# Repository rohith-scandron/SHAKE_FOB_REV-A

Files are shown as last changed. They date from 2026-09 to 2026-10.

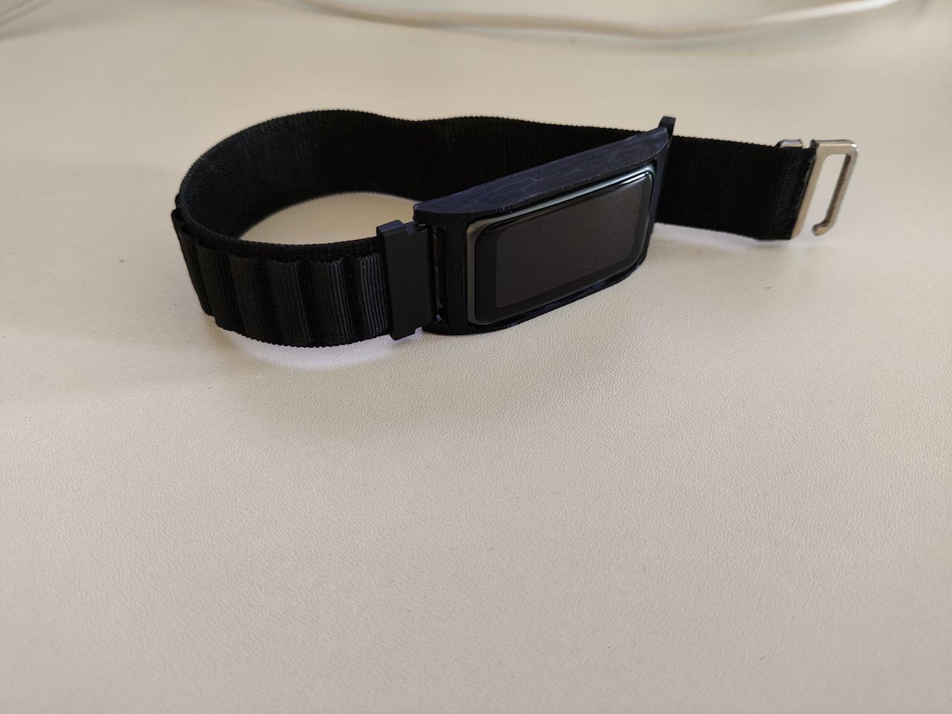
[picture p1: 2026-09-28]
22mm adapter for Huawei band 6 and Honor band 6 - 6260208/images/c12549b3-4bc7-4916-8d0e-d0bb0abc16f8.jpg

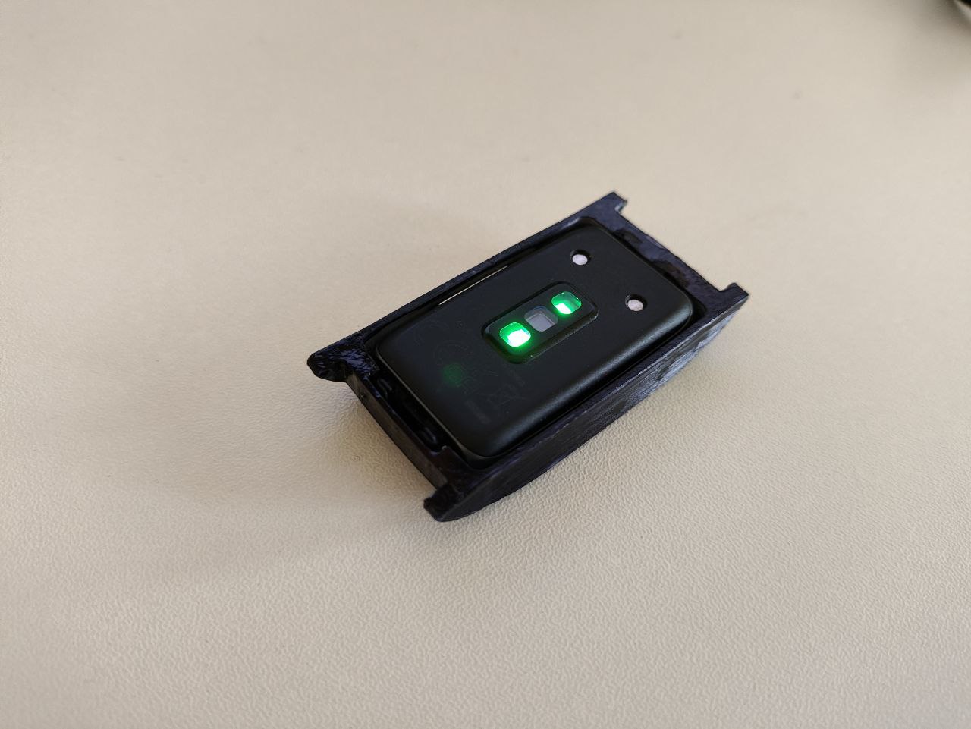
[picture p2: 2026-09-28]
22mm adapter for Huawei band 6 and Honor band 6 - 6260208/images/28dc4d0c-0de9-4cf2-bb80-d6530bd57ec2.jpg

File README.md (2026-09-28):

# SHAKE_FOB_REV-A

A PCB keychain: a shake-activated OLED "digital pet" fob. Sleeps at ~0 µA-class draw
until shaken, wakes and shows an emoji/gif on a small I2C OLED, advances to the next
one on a gentle shake, and sleeps again after 10 s idle. BLE included for a future
companion app to push new gifs. Charges and programs over USB-C. Built for JLCPCB
fab + assembly, optimized for the smallest board that still fits the parts.

## Key specs

| | |
|---|---|
| MCU | ESP32-C3FH4 (bare QFN32, 4 MB integrated flash, RISC-V, BLE 5) |
| Accelerometer | MMA8452QR1 (QFN-16 3×3 mm), transient (high-pass) wake interrupt, no polling needed. Replaced LIS2DH12TR, which is JLC "Standard PCBA only" |
| Charger | MCP73831T-2ACI/OT (SOT23-5), USB-C VBUS in, 147 mA charge rate (R_PROG = 6.8 kΩ) |
| 3V3 rail | XC6206P332MR (SOT23-3), ~1 µA Iq, 200 mA — sized for sleep-dominated duty |
| USB-C | TYPE-C-31-M-12, 16-pin, native USB D+/D− straight to the MCU (no CP2102/CH340) |
| Display | **off-board** — 0.96" 128×64 I2C OLED (SSD1306), 4 bare solder pads (GND/VCC/SCL/SDA), swappable |
| Battery | **off-board** — single-cell LiPo via 2 bare solder pads, user-sourced (the seller's cells come as bare leads, not a pre-terminated JST plug) |
| Buttons | RESET (EN→GND) and BOOT (GPIO9→GND), small SMD tactile — SuperMini-style |
| Board | 2-layer, target ≈ 25–30 × 18–22 mm, JLCPCB fab + SMT assembly |

All ICs above are on the JLCPCB parts library (LCSC part numbers in the BOM notes
below); the display and battery are intentionally *not* SMT parts — they connect
through headers/wires so either can be swapped without touching the PCB.

## BOM / JLCPCB parts library status

Checked against LCSC/JLCPCB directly (not from memory). Prices/stock are a snapshot
— reverify before ordering.

| Ref | Part | LCSC | JLCPCB library | Notes |
|---|---|---|---|---|
| U1 | ESP32-C3FH4, QFN-32-EP (5×5 mm) | C2858491 | Extended | 4233 in stock at check time |
| U4 | MMA8452QR1, QFN-16 (3×3 mm) | C11360 | Extended | Economic-PCBA OK, MSL1, 2,916 in stock. Replaced LIS2DH12TR (C110926: LGA, X-ray required → Standard PCBA only) |
| U3 | MCP73831T-2ACI/OT, SOT23-5 | C424093 | Extended (assumed) | not confirmed live, low risk either way |
| U4 | XC6206P332MR, SOT23-3 | C5446 | **Basic** | ~$0.02, ~1 µA Iq |
| U5 | USBLC6-2SC6, SOT23-6 | C7519 | Extended | USB ESD protection, use the genuine ST part |
| D2 | 1N4148WS, SOD-323 | C2128 | **Basic** | VBUS→SYS. Silicon, not Schottky, for nA reverse leakage on battery (see Power architecture) |
| Q1 | AO3401A P-MOSFET, SOT-23 | C15127 | **Basic** | BAT→SYS load-share switch (Microchip AN1149), ~14 mV drop vs ~0.3 V for a Schottky |
| R15, R16 | 1 MΩ 0402 battery-sense divider → GPIO3 | C26083 | **Basic** | + C19 100 nF; 2.1 µA |
| J1 | TYPE-C-31-M-12, USB-C 16-pin | C165948 | Extended | USB 2.0 subset only (VBUS/GND/D±/CC/SBU) |
| Y1 | 40 MHz crystal, 3225, C_L = 12 pF | **C5380316** (SOSET) | — | imported and confirmed 40 MHz on import; C13738 was mis-picked earlier (turned out to be 16 MHz) and has been removed |
| SW1, SW2 | TS342A2P tactile switch, 4×3×2 mm | C398055 | Extended | RESET + BOOT; checked for a Basic alternative, none found |
| TP1–TP4 | 4× bare solder pad (KiCad `TestPoint` lib) — OLED: GND/VCC/SCL/SDA | generic | n/a, not a real component | replaces a 2.54mm header — no connector to import, no BOM/CPL line |
| TP5–TP6 | 2× bare solder pad (KiCad `TestPoint` lib) — battery: BAT+/GND | generic | n/a, not a real component | replaces the JST-PH connector (below) — the actual battery source is bare leads, not a pre-terminated plug, so there's nothing to keep a connector for |
| ~~J3~~ | ~~S2B-PH-SM4-TB, SMD JST-PH 2-pin~~ | ~~C295747~~ | ~~Extended~~ | **dropped** — imported into the library, then superseded by TP5/TP6 once it turned out the battery isn't sold pre-terminated |
| ANT | Johanson 2450AT18A100E chip antenna | C89334 | — | in stock at check time; decided over a PCB trace, see Antenna below |
| — | RF matching, **chip-side only** (2×C 1.2–1.8pF + 1×L 2.0–3.0nH, 0201, pi network) | generic 0201 | Basic-class, commodity | antenna-side network deliberately dropped for a minimal BOM — see MCU wiring below |
| — | passives (0402/0603/0201 R/C) | generic | Basic-class, commodity | |

**11 Extended parts** after the two free swaps below (JLC BOM check,
2026-09-23): ESP32-C3FH4, MMA8452QR1, MCP73831, USBLC6-2SC6, TS342A2P,
USB-C (C165948), 40MHz crystal (C5380316), antenna (C89334), 1.5pF RF caps
(C1552), 2.2nH (C27122), 0402 LED (C71911). At $3 each that's ≈ **$33** in
loading fees. An earlier count of "5" was wrong. Free swaps with the same
footprint: 10k C25531 → **C25744** (R7–R9, R13, R14) and 100k C25530 →
**C25741** (R10), both Basic. Nothing else on the list has a Basic
equivalent in the same footprint.

**Assembly tier: Economic PCBA.** LIS2DH12TR (and its SC7A20 clone) is
flagged "Standard only" by JLC (LGA → X-ray, MSL3), so the accelerometer was
swapped to MMA8452QR1 (QFN, MSL1, Economic OK). It costs ~$1 more per part and
+3µA of sleep current, but saves ~$17 in Standard setup and the forced edge
rails.

## MCU wiring — verified against Espressif's datasheet + hardware design guidelines

Pulled `esp32-c3_datasheet_en.pdf` and the ESP32-C3 hardware design guidelines
directly (saved in [`datasheets/`](datasheets/)) rather than relying on memory.
Key points that affect the schematic:

- **Power pins**, each needs local decoupling: VDD3P3 (analog/RF, pins 2–3) — 10 µF
  + 0.1 µF (Espressif also suggests an LC filter inductor here for harmonic
  suppression — **dropped**, it's RF-certification margin rather than something
  needed for function, and the linear LDO feeding this rail is already low-noise);
  VDD3P3_RTC (pin 11) — 0.1 µF; VDD3P3_CPU (pin 17) — 0.1 µF; **VDD_SPI (pin 18)** —
  tie directly to 3V3 with a 1 µF cap, since the in-package flash on the FH4 needs
  VDD_SPI ≥ 3.0 V and this pin *cannot* be used as a GPIO on this variant. Add an ESD
  diode + ≥10 µF at the board's main power entrance too.
- **CHIP_EN**: must never float. Standard R=10 kΩ / C=1 µF RC delay to 3V3, RESET
  button pulls it to GND. Espressif's own note: on a slow/battery power rise, RC
  alone can be marginal — accepted as-is here (nearly every hobby ESP32 board ships
  with just RC), flagged as a known limitation rather than adding a supervisor IC.
- **Strapping pins** (GPIO2, GPIO8, GPIO9): GPIO9 gets an explicit pull-up
  (10 kΩ→3V3) *and* the datasheet explicitly warns not to put a capacitor on it, or
  the chip can drop into download mode — matters because BOOT button lands here.
  GPIO2 also gets a 10 kΩ pull-up ("recommended... due to glitches" even though it
  doesn't strictly gate boot mode). GPIO8 gets a 10 kΩ pull-up (R14): download boot needs GPIO8 = 1 (Table 3-3).
- **Crystal**: 40 MHz is compulsory (no internal option), ±10 ppm. Standard 2-pad
  crystal + 2 load caps. Espressif also suggests a 24 nH series inductor on the
  XTAL_P trace for harmonic suppression — **dropped**, same reasoning as the
  VDD3P3 filter above: their own guideline calls the value an "initial
  suggestion... adjust after an overall test," i.e. margin, not a requirement.
  ≥2 mm gap from the chip's clock pin, no vias on the clock trace itself, keep
  it away from the RF trace.
  **Load cap value, corrected:** the formula is `C_L = (C1×C2)/(C1+C2) + C_stray`
  (checked directly against Espressif's live HTML page — the PDF's text extraction
  had jumbled the fraction and put C_stray inside the denominator, which gave a
  wrong answer the first time around). With C1=C2=C, C_stray≈3 pF (typical PCB
  estimate), and our crystal's C_L=12 pF: `C = 2×(C_L − C_stray) = 2×(12−3) =
  18 pF`. **C1=C2=18 pF**, not the earlier 27 pF.
- **RF matching — deliberately minimal, one network not two.** Espressif's
  checklist describes two possible networks: a chip-side CLC ("must be
  placed close to the chip," no exception given) and a separate antenna-side
  CLC (which *does* have an explicit skip condition, if the antenna's
  impedance is already known to be 50Ω). The fully-by-the-book version of
  this design would have both — went there briefly, then cut back down by
  explicit request for a minimal board. **Kept the chip-side network only**
  (Espressif's generic bare-chip pi values: 1.2–1.8 pF / 2.0–3.0 nH /
  1.8–1.2 pF, 0201): a bare silicon RF pin with no matching at all is
  typically a bigger mismatch than a purpose-built antenna's nominal
  impedance drifting somewhat from board-layout differences, so this is the
  half that protects against the larger problem. **Dropped the antenna-side
  network** (Johanson's own T-network for this specific antenna, which their
  datasheet does recommend — see `docs/SCHEMATIC_BOM.md` Block 4e for the
  values, kept there for reference even though not populated). **Accepted
  trade-off, not a free simplification**: the antenna's real impedance on
  this board won't exactly match Johanson's 50Ω spec (measured on their own
  eval board), and that drift goes uncorrected — some range/efficiency traded
  for a smaller BOM, reasonable for a close-range, non-certified BLE keychain.

  Full derivation and the dropped network's values (kept for reference) in
  `docs/SCHEMATIC_BOM.md` Block 4e.
- **USB (GPIO18/19 = D−/D+)**: 22 Ω series resistors close to the chip; footprints for
  optional shunt caps and a D+ pull-up left unpopulated unless startup instability
  shows up on the bench.

### Antenna — decided: Johanson chip antenna

**Decision (confirmed with user 2026-09-22):** Johanson **2450AT18A100E** ceramic
chip antenna, LCSC C89334, in stock, ≈$0.54. The guidelines are explicit that a PCB
trace antenna needs EM simulation and real-world validation to get right — Espressif
doesn't publish a generic copy-paste trace for an arbitrary board shape, and
freehand-copying the SuperMini's antenna from a photo onto a different stackup has a
real chance of detuning it with no way for us to check. A chip antenna is a
purchasable SMD part with a vendor-validated footprint and matching network from
Johanson's own application note — a few cents of BOM for a much higher chance the
radio just works, with no lab equipment required. Still needs a copper/component
keep-out under and around it (per Johanson's app note), smaller than a full
PCB-trace keepout, so it doesn't reopen the board-size problem.

Note: the SuperMini board itself uses **ESP32-C3FN4**, which is now
**NRND (Not Recommended for New Designs)**. Good thing this board isn't cloning its
BOM — FH4 (already our pick) is the current, stocked part; "H" vs "N" also aren't
footprint-compatible, so a literal SuperMini clone wouldn't have dropped in anyway.

## Power / control architecture

```
USB-C VBUS (5V) ──┬──► MCP73831 ──► BAT ──► battery pads (TP5/TP6)
                  │                   │
                  │                   ├──► R15/R16 1M:1M ──► GPIO3 (battery sense)
                  │                   │
                  │                   └──► Q1 AO3401A (D→S) ──┐
                  │                          gate ◄── VBUS    │
                  ├──► D2 1N4148WS ─────────────────────────┴──► SYS ──► XC6206 ──► 3V3 ──► ESP32-C3, MMA8452Q, OLED
                  └──► R13 10k ──► GND (Q1 gate pull-down)
   CC1/CC2 ──5.1k──GND
   D+/D− ──────────────► MCU native USB

MMA8452Q INT1 ──► GPIO0 (RTC-capable, deep-sleep wake source, active-high)
MMA8452Q INT2 ──► GPIO1 (spare, wired for future use)
```

**Load sharing (Microchip AN1149).** USB present: Q1's gate is at VBUS, so
it's off. D2 feeds SYS and the battery charges alone, which lets the
charger terminate properly. USB absent: R13 pulls the gate low, Q1 turns
fully on, and SYS = BAT − ~14 mV. The board runs from USB with no battery
installed, and the battery never sees raw VBUS. Full reasoning and pin-out
are in [`docs/SCHEMATIC_BOM.md`](docs/SCHEMATIC_BOM.md) Block 2.

**Wake GPIO: GPIO0** (physical pin 4, `XTAL_32K_P`). ESP32-C3's RTC-IO pins — the
only ones that can wake the chip from deep sleep — are GPIO0–GPIO5 (the pins
powered by VDD3P3_RTC; datasheet §2.5, Table 2-1). Ruled out the others: GPIO2 is
a strapping pin (already has a pull-up for glitch immunity — simpler not to also
share it with an interrupt input at boot); GPIO4/GPIO5 double as JTAG (MTMS/MTDI);
GPIO0/GPIO1 are the pins for the *optional* 32.768 kHz RTC crystal, which this
board isn't populating, and the datasheet explicitly says those pins "can be used
as GPIOs" when that crystal is skipped (§1.3.5) — so GPIO0 is genuinely spare, not
a compromise. The MMA8452Q's INT pins are push-pull and always driven, so
**no pull resistor on either INT pin**. The old 100 kΩ pull-down (R10) is
deleted. It would fight the chip's power-on default (active-low, so idle
high) and waste 33 µA until firmware sets IPOL = 1.

- **Wake-on-shake is hardware, not polled.** The MMA8452Q's transient detector
  (high-pass filtered, so gravity and slow tilting are ignored) runs at 12.5 Hz in
  low-power mode (6 µA). A vigorous shake above ~1.5 g latches INT1, which wakes the
  ESP32-C3 from deep sleep. Once awake, firmware reprograms the same transient channel
  to a gentle threshold (~0.5 g at 50 Hz) for "next gif", then restores the wake
  settings before sleeping. There's only one transient channel, and it's all both
  gestures need. INT2 is wired but spare. Register values are in
  docs/SCHEMATIC_BOM.md Block 5.
- **Why a P-FET and not a second Schottky on the battery side.** The earlier
  D2+D3 diode-OR put a ~0.3V Schottky drop in the battery path. That raised
  the usable-battery floor to ~3.45V active, or ~3.6V during BLE. Q1 drops
  ~14mV, which puts the floor at **~3.1–3.2V active and ~3.3V during BLE**.
  Below that a LiPo has only a few % left, so this is effectively the whole
  cell. D2 is a **silicon** 1N4148WS on purpose: on battery it sits
  reverse-biased at ~4V, and the 1N5819WS Schottky leaks ~6–7µA there at
  25°C (read off its datasheet curve). That's over half the sleep budget.
  The 1N4148WS leaks nA. Its higher forward drop only applies on USB, where
  there's headroom to spare.
- **XC6206 (200mA) stays, with two firmware rules.** The ESP32-C3 datasheet
  only tables Wi-Fi TX current: **335mA peak @ 21dBm**, far over 200mA. So:
  **never enable Wi-Fi**, and **cap BLE TX at 0dBm**. The datasheet has no
  BLE figure, so measure the real peak at bring-up. Normal operation (CPU +
  OLED, no radio) is ~40–45mA, comfortably inside the rating. RT9013 (500mA)
  was rejected because its ~25µA Iq would roughly triple sleep current. An
  earlier "~650mV droop at 10µF, go to 47µF" derivation was withdrawn: it
  rested on an invented 50µs LDO response time. C9 = 10µF + C10 = 0.1µF is
  Espressif's reference decoupling for VDD3P3.
- **GPIO8 pull-up (R14, 10k to 3V3).** It's a strapping pin, and download
  mode needs GPIO8 = 1. In deep sleep the USB-CDC port disappears, so BOOT +
  RESET is the recovery path, and it must be reliable.
- **Battery sense (R15/R16/C19 → GPIO3).** Lets firmware stop waking the
  display below ~3.3V and show a battery icon, instead of brownout-looping
  the cell down to its protection cutoff.
- **No physical power switch.** Sleep budget, every figure sourced from the actual
  datasheet (see Battery life below, not hand-waved): **≈14.4 µA typical, board only**. Shelf
  drain from our own electronics is a non-issue at that level — LiPo self-discharge
  dominates over it. Revisit if a firmware bug (e.g. polling instead of interrupt-driven
  wake) makes this wrong.
- **No onboard battery protection IC.** Assumes the LiPo cell has its own protection
  PCB, which is standard for small hobby packs. **Confirm this once a battery is
  picked** — an unprotected cell needs a DW01+FS8205 (or similar) added.

## Battery life — 300 mAh cell

Every current figure below is from the actual component datasheet (all saved in
[`datasheets/`](datasheets/)), not estimated:

| Contributor | Typ. current | Source |
|---|---|---|
| ESP32-C3 deep-sleep (RTC timer + RTC memory only) | 5 µA | Espressif datasheet, Table 5-9 |
| MMA8452Q low-power mode, ≤12.5 Hz ODR (watching for a shake) | 6 µA | NXP datasheet, Table 3 |
| XC6206 LDO quiescent current | 1.0 µA | Torex XC6206 series spec (converged across distributor-hosted copies; direct Torex PDF was blocked from this environment) |
| MCP73831 leakage into BAT when USB is unplugged | 0.25 µA (2 µA max) | Microchip datasheet, "Battery Discharge Current," V DD < (V BAT − 50 mV) condition — **not** the 53 µA figure floating around online, which is a different spec ("Charge Complete, No Battery," current from V DD, not from the battery) |
| D2 reverse leakage, 1N4148WS @ ~4 V | ~0.01 µA | nA-class. A 1N5819WS here would be ~6–7 µA (Hottech datasheet curve) |
| Battery divider R15 + R16 (2 MΩ) | 2.1 µA | 4.2 V / 2 MΩ |
| Q1 / R13 | 0 | VBUS is 0 V on battery |
| **Total sleep current (board)** | **≈14.4 µA typ** | **+ OLED module in display-off (not budgeted — measure it)** |

**Pure shelf life** (never touched): the cell's own protection IC (~3 µA,
DW01-class) and LiPo self-discharge (~1–2 %/month ≈ 4–8 µA equivalent) are
as big as the board itself. A realistic shelf estimate, cell untouched, is
**~1–1.5 years**, minus whatever the OLED draws asleep.

**Real-world battery life is dominated by usage, not sleep current.** Per wake event
(OLED + MCU active for the spec'd 10 s, no radio — BLE is rare per your last note):
ESP32-C3 active ≈ 20 mA (Espressif Table 5-8, Modem-sleep/CPU-running range is
13–23 mA depending on clock and load) + SSD1306 OLED ≈ 20 mA (content-dependent,
typical hobbyist figure, not datasheet-sourced) ≈ **40 mA for 10 s ≈ 0.11 mAh/wake**.

| Wakes / day | mAh/day (wakes + sleep baseline) | Battery life |
|---|---|---|
| 10 (a few deliberate check-ins) | ~1.6 | **~6 months** |
| 30 (frequent play + some incidental jostling) | ~3.8 | **~2.5 months** |
| 100 (worst case — threshold too sensitive, triggers on walking/bag movement) | ~11.6 | **~26 days** |

**The single biggest lever on battery life is the shake-detection threshold**, not
any hardware choice already made — a threshold tuned to reject normal carrying
motion (walking, keys jingling in a pocket) versus one that only catches a
deliberate vigorous shake is roughly a 4–10× difference in real-world runtime. This
needs bench tuning once hardware exists; it can't be fully predicted on paper.

## Architecture decisions

| Decision | Rationale |
|---|---|
| Bare ESP32-C3FH4, not the MINI-1 module | User pointed at the ESP32-C3 "SuperMini" board as the size reference — that board uses the bare chip, not the pre-shielded module. Smaller and cheaper, at the cost of doing the RF front-end ourselves (see MCU wiring / Antenna below). |
| Chip antenna, not a hand-copied PCB trace | Confirmed with user. Espressif's own guidelines say a PCB trace antenna needs EM simulation + real hardware validation, which we can't do. A vendor-validated ceramic chip antenna (Johanson 2450AT18A100E, ~$0.54) is a few cents for much higher confidence it just works — reasonable even though BLE itself is a rarely-used, nice-to-have feature here, precisely because it's cheap enough not to be worth the risk either way. |
| Antenna keepout: tighter than Espressif's full 15 mm recommendation | 15 mm clearance in every direction would dominate the board size on something this small. The chip antenna's own keep-out (per its application note) is smaller than the bare-trace figure, and SuperMini-class boards prove a tight keepout still works for short-range BLE. Accepted trade: reduced RF range, irrelevant for a phone held next to a keychain. |
| MMA8452QR1 over LIS2DH12TR | LIS2DH12TR (and the SC7A20 clone) are JLC "Standard PCBA only" (LGA → X-ray, MSL3). The MMA8452Q is QFN, MSL1, Economic-assemblable, in stock, and has a high-pass transient detector made for shake wake. Costs: 3×3 mm vs 2×2 mm, ~$1 more, and 6 µA vs 3 µA asleep. The 2×2 MMA8652FC/MMA8653FC would be better but were out of stock (2026-09-23). |
| XC6206P332MR over AMS1117 / a plain 662k-style LDO | JLCPCB Basic part, ~1 µA quiescent current. AMS1117's ~5 mA quiescent draw alone would blow the sleep budget by >250×. |
| MCP73831 over TP4056 | SOT23-5 is smaller than TP4056's SOP-8, and board area is the constraint here. Trade-off: no onboard load-disconnect/protection — see the protection-IC note above. |
| Native USB (no CP2102/CH340 bridge) | ESP32-C3 has an on-chip USB-Serial-JTAG controller; wiring D+/D− straight to it gives USB-CDC programming and a serial console for free, and drops a chip + its passives from the BOM. |
| OLED and battery off-board via solder pads | Per instruction — keeps the option to change display size later without a respin, and neither part is realistically JLCPCB-SMT-placeable-and-reliable at this end of the market anyway (small COG/FPC displays are usually hand-placed even on boards that do put them in the BOM). Pads instead of connectors on both, once it was clear neither the OLED nor the battery arrives pre-terminated for one. |

## Open items (before this is ready for schematic capture)

**Resolved this pass:**
- ~~Antenna approach~~ → **decided and confirmed:** Johanson 2450AT18A100E chip antenna
- ~~40 MHz crystal~~ → **SOSET C5380316**, confirmed 40 MHz on import (an earlier candidate, YXC C13738, turned out to be 16 MHz and was removed from the library)
- ~~Library import~~ → all 9 distinctively-numbered parts imported into `ESP32_C3_FOB/libs/lcsc/` via the LCSC manager plugin, symbol+footprint+3D model each — see `docs/SCHEMATIC_BOM.md` for the KiCad symbol/footprint names
- ~~RF matching network~~ → settled on **chip-side pi network only** (Espressif's generic values), one network not two — antenna-side T-network (Johanson's values) deliberately dropped for a minimal BOM, accepted as a real trade-off not a free simplification. VDD3P3 filter and crystal series inductors also dropped as unneeded RF-certification margin.
- ~~JLCPCB part availability~~ → full table above, all parts orderable today
- ~~Sleep-current budget~~ → re-derived from actual datasheets: ≈12.25 µA typ (see Battery life) — corrects the earlier hand-waved 17 µA figure
- ~~Battery life estimate~~ → see Battery life section; dominated by wake frequency, not sleep current
- ~~Wake GPIO~~ → **GPIO0**, see Power/control architecture above for why
- ~~R_PROG~~ → **battery confirmed at 300 mAh; R_PROG = 6.8 kΩ → 147 mA (≈0.5C)**,
  from MCP73831 datasheet §5.2.2: `I_REG(mA) = 1000 × V / R_PROG(kΩ)`. 0.5C chosen
  over 1C (300 mA, R_PROG = 3.3 kΩ) for better cycle life on a small cell — swap one
  resistor if faster charging matters more than longevity.

**Still open:**
- **Board outline and JLCPCB panelization** — anything under 70×70 mm needs a panel
  (mouse-bites or V-cut) for SMT assembly; this board will need one designed once
  the outline is fixed.
- Charge-status LED on MCP73831 STAT — included by default, cut if it doesn't fit.
- CHIP_EN RC-only power-up timing on battery power — accepted risk, see MCU wiring above.

## Repository layout

| Path | Contents |
|---|---|
| `SHAKE_FOB_REV-A.kicad_pro/.kicad_sch/.kicad_pcb` | KiCad project (not created yet) |
| `libs/lcsc/` | Project-local LCSC symbols/footprints/3D models |
| `docs/` | Working notes |

## Status

**Architecture and BOM defined. Schematic capture not started.**
# SHAKE_FOB_REV-A

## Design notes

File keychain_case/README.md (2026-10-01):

# HUAWEI Band 6 keychain case

A keychain frame for the HUAWEI Band 6: the four sides only, no strap mounts, flat ends
and a keyring loop. The screen and the heart-rate sensor stay uncovered.

| File | |
|---|---|
| `band6_keychain_case.step` | CAD (STEP) |
| `band6_keychain_case.stl` | ready to slice |
| `band6_keychain_case.py` | CadQuery source, all sizes at the top |
| `preview.png` | renders |

Outside size: **27.4 × 56.7 × 10.2 mm** (including the loop).

## Fit

The fit geometry was measured from the proven Band 6 frame
[thing:6260208](https://www.thingiverse.com/thing:6260208) and rebuilt as a clean solid.
The rebuild matches the reference surface to a median deviation of 0.003 mm.
- 25.38 × 42.6 mm cavity with 1.0 mm side walls and the same curved screen-side edge
- button opening in the same spot
- the two internal tongues that clip into the watch's own strap slots. These are what
  hold the watch in the frame, so they are kept.

What changed: the 22 mm spring-bar ears are removed, the ends are closed flat, the four outer
corners are rounded (5 mm radius), and a round keyring eye is added. The eye has a wide triangular base
so the pull goes into the solid end corners.

With the keyring at the top and the screen facing you, the button opening is on the right
(`BTN_SIDE = 1`; `-1` moves it to the other wall, `RING_END` swaps the loop's end). It is a round eye (9 mm outside,
4.6 mm hole) set close to the case, so it sticks out only 7.2 mm past the case end.

A 0.8 mm inward ledge runs along the back edge of the two long sides (`LIP_W`, `LIP_T`).
The short ends have no ledge, so the watch can be tilted in end first past the tongues. The watch is pushed in
from the screen side and stops on it, and it can't fall out the back. The ledge is added
under the old back face, so the watch sits at the same height and the tongues still line
up with its strap slots; the case is 0.8 mm thicker. The heart-rate sensor stays uncovered.

## Printing

- Print with the flat back face on the bed. It needs no supports: the tongue pockets are
  short bridges.
- Material: PETG or PLA (the reference was printed rigid), 0.4 mm nozzle, 0.12–0.16 mm
  layers, 3+ walls.
- Fitting: from the screen side, slide one end's tongue into the watch's strap slot, then
  press the other end in until it clicks and the watch sits on the back ledge.
- If it is too tight, set `CLEAR = 0.1` in the script and re-run
  `python3 band6_keychain_case.py`.

## License

Derived from "22mm adapter for Huawei band 6 and Honor band 6" by M7md_says_hello
(thing:6260208), licensed **CC BY-SA**. This derivative is shared under the same license.

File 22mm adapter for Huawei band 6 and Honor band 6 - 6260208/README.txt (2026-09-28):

22mm adapter for Huawei band 6 and Honor band 6 by M7md_says_hello on Thingiverse: https://www.thingiverse.com/thing:6260208

Summary:
22mm adapter for Huawei band 6 and Honor band 6

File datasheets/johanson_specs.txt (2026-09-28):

=== PAGE 1 ===
P/N:  2450AT18A0100001E 
Legacy P/N: 2450AT18A100 
Doc# 36S0021A 
Page 1 of 6 / Revision 4.0 
Datasheet: 2450AT18A0100001E 
johansontechnology.com 
4001 Calle Tecate • Camarillo, CA 93012, USA • +1.805-389-1166 
2024 Johanson Technology, Inc.  All Rights Reserved 
2.45 GHz RF Chip Antenna 
•
2.4 – 2.5 GHz Operational frequency
•
Bluetooth, WLAN
•
SMD, EIA 1206
•
Corner mount
•
RoHS compliant and AEC-Q200 Qualified available
Johanson Technology, Inc. (JTI) miniature RF ceramic chip antennas 
are made using Low Temperature Co-fired Ceramic (LTCC) technology 
which has the ability to embed low and high dielectric constants inside 
our antenna. This  enables our components to have high detuning 
resilience and stability over extreme temperatures (~2ppm). 
General Specifications1 2 
Maximum Ratings 
1 Typical value represents average measurement at 25°C. Min./Max. values represent measurements over specified operating temperature. 
2 General specifications measured on Johanson’s evaluation board P/N 2450AT18A0100001CE1.  
Passband Frequency (MHz) 
2400 - 2500 
Impedance (Ω) 
50 
Return Loss (dB) 
9.5 Min. 
Peak Gain (dBi) 
1.5 Typ. 
Average Gain (dBi) 
0.0 Typ. 
Average Radiated Efficiency (%) 
74 
Power Capacity (W) 
3 Max. (CW) 
Operating Temperature (°C) 
-40 to +125
Recommended Storage Conditions post-installation (°C) 
-40 to +125
Recommended Storage Conditions and Period for Unused T&R Product 
45% - 75% RH 
+5 to +35 °C
18 Months Max. 
PCB Corner 
Recommended mounting locations for this antenna 
=== PAGE 2 ===
P/N:  2450AT18A0100001E 
Legacy P/N: 2450AT18A100 

Doc# 36S0021A 
Page 2 of 6 / Revision 4.0 
Datasheet: 2450AT18A0100001E 
 
johansontechnology.com 
4001 Calle Tecate • Camarillo, CA 93012, USA • +1.805-389-1166 
2024 Johanson Technology, Inc.  All Rights Reserved 
Mechanical Dimensions  

Terminal Configuration3 

3 The termination type is Nickel Tin. Go to: https://www.johansontechnology.com/ipcsoldering-profile for Typical Soldering Profile. 
 This terminal must be soldered for anchoring and mechanical stability. 
Pin Number 
Function 
1 
Feed 
2 
NC 
Bottom view 
Top view 
Side view 
② 
① 
a 
a 
L 
W 
T 
L
0.126
±
0.008
3.20
±
0.20
W
0.063
±
0.008
1.60
±
0.20
T
0.051
1.30
a
0.020
±
0.012
0.50
±
0.30
Inches
Millimeters
 +0.10/-0.20
 +0.004/-0.008

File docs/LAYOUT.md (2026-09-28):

# Layout guide — SHAKE_FOB_REV-A

Ref-des match the actual schematic. Rules are sourced from Espressif's
ESP32-C3 hardware design guidelines §1.4 and the Johanson 2450AT18A100E
datasheet (p.3), both in `datasheets/`.

---

## 0. Before placing anything

| Step | What |
|---|---|
| 1 | **Add C20 (1µF, C52923) + C21 (10nF, C15195) on VDDA pins 31/32** in the schematic, then press F8 (Update PCB from Schematic). The PCB currently has 48 footprints; the schematic has 55, going to 57. |
| 2 | Stackup: **2 layers, 1.6mm** (the cheap default, kept on purpose for a hobby board). |
| 3 | **Shrink the existing 3.3V zone on F.Cu.** It currently covers the whole board. Redraw it as a bounded region (see Zones below), because a board-wide 3.3V pour puts 3.3V copper right against the RF trace, the crystal and the antenna. |
| 4 | Zones: **GND on both layers** plus the bounded 3.3V region on top. B.Cu is the ground plane, so keep it as unbroken as possible. |
| 5 | **Change R1, R2 (5.1k) and R6 (1k) from 0201 to 0402**, see the box below. |
| 6 | Enter the Board Setup values in section 0a. |

> **Why 0201 has to go.** JLC **Economic PCBA** (the cheap one) only
> places parts down to **0402**. A single 0201 forces **Standard PCBA**,
> which needs a board ≥70×70mm or a panel with edge rails, plus fiducials
> and a higher setup fee. Every other part on this board is already 0402 or
> larger.
> - R1, R2 → 5.1kΩ 0402 **C25905** (Basic)
> - R6 → 1kΩ 0402 **C11702** (Basic)
>
> For the footprint, reuse any R0402 footprint already in your lib (e.g.
> `lcsc_footprints:C25531_R0402`). The land pattern is identical.
>
> Economic PCBA also means: one side only (already the plan), 0.8–1.6mm
> thick, board ≥10×10mm, and **no fiducials or edge rails needed**.

---

## 0a. Board Setup values (JLC 2-layer, 1oz, 1.6mm)

JLC limits below are from jlcpcb.com/capabilities (checked 2026-09-23).
The chosen value leaves margin over the absolute minimum, because
running at the limit is where yield drops.

### Design Rules → Constraints

| Setting | JLC min | **Use** |
|---|---|---|
| Minimum clearance | 0.10 | **0.15** |
| Minimum track width | 0.10 | **0.15** |
| Minimum connection width | — | **0.15** |
| Minimum annular width (via) | 0.05 | **0.10** |
| Minimum via diameter | 0.25 | **0.50** |
| Copper to hole clearance | 0.20 (via hole → track) | **0.20** |
| Copper to edge clearance | 0.20 (routed edge) | **0.30** |
| Minimum through hole | 0.15 | **0.30** (0.3mm drill is JLC's no-extra-cost size) |
| Hole to hole clearance | 0.20 (via), 0.45 (pad holes) | **0.25** |
| Silk: min text height / thickness | 1.0 / 0.15 | **1.0 / 0.15** |
| Silk to pad (mask) clearance | 0.15 | **0.15** |

### Design Rules → Solder Mask/Paste

| Setting | **Use** | Why |
|---|---|---|
| Solder mask expansion | **0** | JLC plots your mask 1:1 |
| Solder mask min web width | **0.10** | JLC min mask bridge, green |
| Tent vias | **on, both sides** | JLC fills tented vias with mask, so no shorts under parts |

With a 0.5mm pitch QFN/LGA, the pad gaps are ~0.2–0.25mm, above the 0.1mm
bridge, so mask dams stay between pins.

### Pre-defined Sizes — 3 widths, 1 via

| Tracks | Via (dia / drill) |
|---|---|
| **0.2** signals · **0.4** power · **0.6** RF trace only | **0.6 / 0.3** everywhere, including the EP grid |

### Net Classes — just 2

| Class | Track | Clearance | Via | Nets |
|---|---|---|---|---|
| **Default** | 0.2 | 0.15 | 0.6 / 0.3 | everything not listed below |
| **Power** | 0.4 | 0.2 | 0.6 / 0.3 | `VBUS`, `BAT`, `V_SYS`, `3.3V`, `GND` |

- **0.2mm fits everywhere,** including the QFN and LGA pads (~0.25mm wide),
  so no neck-downs are needed. USB D+/D− and the crystal lines are just
  Default, routed carefully by hand.
- **0.4mm for power** handles ~1A on 1oz outer copper. The biggest current
  here is ~200mA.
- **RF is drawn by hand at 0.6mm.** It's one ~4mm trace, so it doesn't need
  its own class. With the 0.2mm zone gap it comes out at ~63Ω. That's fine
  at this length (a true 50Ω line would be ~1.2mm wide).
- **By hand, no DRC rule:** no vias on the RF trace or the crystal lines.

### Zones (fills)

| Zone | Layer | Area | Priority |
|---|---|---|---|
| **GND** | B.Cu | whole board | 0 |
| **GND** | F.Cu | whole board | 0 |
| **3.3V** | F.Cu | **bounded region only**, see below | 1 (higher) |

Settings for all zones: clearance **0.2**, min width **0.2**, thermal
reliefs (spoke 0.3, gap 0.2), remove islands **always**. For U3, C14 and
C15, set zone connection to **Solid** in the footprint properties.

**3.3V fill: allowed, but fence it in.** Draw the 3.3V zone outline only
around the LDO → C9 → ESP32 power-pin area. Keep it **off**:
- the antenna corner, the RF trace and C14/L3/C15
- the crystal and C12/C13
- the USB D+/D− pair

Those areas need **top-layer GND** next to them: the RF trace uses the top
GND as its side walls, and the crystal needs a clean ground ring. The
whole-board top GND zone automatically fills everything the 3.3V zone
doesn't cover, because the higher-priority zone wins where they overlap.
The bottom layer stays 100% GND, which is Espressif's 2-layer rule.

### Antenna keepout

Rule area 6.5 × 6.5mm at the antenna corner, **F.Cu + B.Cu**. Tick keep out
*tracks*, *vias*, *copper pours*. **Untick** *pads* and *footprints*, so
AE1 itself can sit inside it.

### Vias in the QFN EP

9 vias, **0.6 / 0.3**, 3×3 grid at ~1.1mm pitch inside the 3.7mm EP. These
can't be tented because they're in a pad. A little solder wicks down them,
which is normal and harmless on a ground/thermal pad.

**2-layer rules (Espressif §1.4.1–1.4.2, two-layer design):**
- **B.Cu = ground.** Don't place parts on the bottom and keep traces there
  to a minimum. Any bottom trace must be short, and **never under the chip,
  the crystal, the RF trace or the antenna feed.** A long bottom trace cuts
  the ground plane and the return current has to detour around it.
- **Route power on the top layer**, including the 3V3 branches to each
  chip pin. Use vias to the bottom only when there's no other way.
- Put GND vias everywhere between top-layer pour and bottom plane: at every
  cap's GND pad, around the RF trace, around the crystal, and along the
  board edges.

**RF trace width on 2-layer:** a true 50Ω coplanar trace on 1.6mm FR4 is
~1.2mm wide with the 0.2mm zone gap (calculated for εr 4.4–4.6). A 0.6mm
trace is ~63Ω. At 2.44GHz the wavelength in this line is ~76mm, so a trace
under ~4mm (λ/20) is electrically too short for 63Ω vs 50Ω to matter.
**Decision: route it at 0.6mm and keep it short** by putting U3 right next
to the antenna corner. If the RF trace can't be kept short, make it
1.0mm wide instead.

---

## 1. Floorplan — decide the stack first

The 0.96" OLED module is ~27×28mm, so the fob is at least that size anyway.
The PCB can be the same width at no size cost.

**The one hard mechanical rule:** the antenna corner must **not** sit
behind the OLED module or the LiPo pouch. Both are large ground/metal
sheets and will detune it. Let the antenna corner stick out ~7mm beyond the
display/battery stack.

```
 ┌───────────────────────────┐
 │ (O)            ┌─────────┐│  ← 6.5×6.5mm corner: NO copper on ANY layer
 │ keyring        │   AE1   ││     antenna long axis along the board edge,
 │ hole           └────▲────┘│     feed pin 1 toward the ground plane
 │                     │ π   │  ← C15 / L3 / C14 right at U3 pin 1
 │   X1 ◄2mm+  ┌─────┐─┘     │
 │             │ U3  │   U4  │
 │   C20/C21   └─────┘       │
 │  OLED pads: GND VCC SCL SDA (2.54mm pitch)
 │  U2  Q1 D2   U1  LED1     │
 │ SW1 SW2   BAT+ BAT−   D1  │
 │          [ USB-C ]        │
 └───────────────────────────┘
```

- **Antenna end = far end from USB-C.** The USB shell and cable are metal.
- **Keyring hole:** NPTH ~4mm, in the top corner *opposite* the antenna,
  ≥2mm of board to the edge, copper keepout ~1mm around it. Never put it at
  the USB end, or the ring blocks the plug.
- **Buttons (SW1 RESET, SW2 BOOT)** must stay reachable after the OLED and
  battery are mounted. Put them at the USB end, which has to stay exposed
  anyway.
- **All SMT on the top side.** A single side means one assembly pass,
  which is cheaper.

---

## 2. Block by block

### RF + antenna (do this first, everything else fits around it)

| Rule | Source |
|---|---|
| AE1 in a board **corner**, long axis parallel to the edge, ~1mm in from it | Johanson p.3 |
| **6.5 × 6.5mm copper-free area** around AE1 on **both layers**. Use a KiCad Rule Area: keep out tracks, vias and zone fill, but allow footprints | Johanson p.3 |
| AE1 pin 1 (feed) faces the ground plane. Pin 2 (NC) gets its pad and solder but no connection | Johanson p.2 |
| U3 **pin 1 corner points at the antenna** | Espressif §1.4.4 |
| C15 (shunt, at pin 1) → L3 (series) → C14 (shunt) as close to pin 1 as possible, **zigzag** (the two caps not oriented the same way) | Espressif §1.4.4 |
| No 2nd-harmonic stub needed: "not required for 0402 and above", and these are 0402 | Espressif §1.4.4 |
| C14/C15 GND pads: a via right at each pad, solid connection (no thermal spokes) | Espressif §1.4.2 |
| RF trace from C14 to AE1: **top layer only, no vias, constant width, no branches, ≤4mm**, GND via fence on both sides at ~1mm pitch, solid bottom GND under it | Espressif §1.4.4 |
| Nothing else routed near the RF trace, on any layer | Espressif §1.4.9 |

### ESP32-C3 (U3) — pin sides and what goes on each

| Side | Pins | Place here |
|---|---|---|
| 1 | 1 RF · 2,3 VDD3P3 · 4,5 INT1/INT2 · 6 GPIO2 · 7 EN · 8 VBAT_SENSE | π network at pin 1, **C9 + C10 at pins 2/3**, R8 at 6, R7+C6 at 7, R15/R16/C19 near 8 |
| 2 | 9 SDA · 10 SCL · 11 RTC · 14 GPIO8 · 15 BOOT | C8 at 11, R14 at 14, R9 at 15. I2C heads toward U4 and the OLED pads |
| 3 | 17 VDD3P3_CPU · 18 VDD_SPI · 19–24 NC | C7 at 17, C11 at 18. No routing on this side, so it's free for the 3V3 feed |
| 4 | 25,26 USB · 29,30 XTAL · 31,32 VDDA | R3/R4 near 25/26, crystal off 29/30, **C20 + C21 at 31/32** |

- **EP (pin 33): ≥9 GND vias** (3×3 grid, 0.3mm drill), solid to the
  pour. Use a windowed paste pattern (~4 squares) so the QFN doesn't float
  on a solder blob.
- **Power:** 3V3 enters at **C9 (10µF) by pins 2/3**, then branches in a
  star **on the top layer** around the outside of the chip to each pin's
  own cap. Espressif: "a 10µF capacitor before the power trace enters the
  chip… then branch out in a star-shaped layout". Keep U2 close to that side
  so C9 doubles as the "main power entrance" cap. Side 3 (pins 19–24, all
  NC) has no other routing, so it's the natural path for the 3V3 branch to
  pins 17/18.
- Every decoupling cap sits on its own pin with a GND via at its pad.
  Cap first, then the via to the pin, never via → cap.

### Crystal (X1, C12, C13)

- **≥2mm gap between the crystal and the chip**, on the pin 29/30 side,
  toward the pin 25 end so it stays away from the RF corner.
- **No vias on XTAL_P/XTAL_N.** Short, direct, top layer.
- C12/C13 at the crystal's own pads, GND via right at each.
- **Nothing routed under the crystal on any layer.** Stitch GND vias
  around it. Keep it away from the antenna and from USB.

### USB (USBC1, D1, R1–R4)

- USB-C flush with the board edge, using the footprint's board-edge marker.
  EH shell tabs go to GND.
- **D1 (USBLC6) right behind the connector**, with a short, fat GND via.
- Tie DP1+DP2 and DN1+DN2 right at the connector. That needs one short
  bottom-layer crossover (every USB-C footprint does). Keep it under ~2mm,
  with a GND via next to each signal via.
- R3/R4 (22Ω) **near the chip side** (Espressif §1.4.8).
- D+/D− routed as a pair, equal length, on top over unbroken bottom GND.
  The ESP32-C3 is USB Full-Speed (12Mbps), so on traces this short,
  keeping the pair together matters more than hitting exactly 90Ω. On
  2-layer 1.6mm, true 90Ω isn't practical anyway.
- R1/R2 (CC 5.1k) right at the CC pins.

### Power path (U1, U2, Q1, D2, R13, C1–C5, LED1)

- Cluster at the USB end: USBC1 → C1/C3 → U1 and D2/Q1 → V_SYS → U2 → 3V3
  heading toward U3's pin 2/3 side.
- **C4 at U2 Vin, C5 at U2 Vout**, both within ~1mm of the pins.
- **C2 (10µF) right at U1 VBAT (pin 3).** It's the charger's stability cap.
- Q1, D2 and R13 next to each other between U1 and U2. Tracks at 0.4mm.
- U1 dissipates up to ~0.3W while charging, so give its VSS pin a copper
  pad and a couple of GND vias.
- BAT+ / BAT− pads (TP5/TP6) on an edge near U1, with **"+" and "−"
  clearly on silkscreen**. Reversed polarity kills the charger.

### Accelerometer (U4, C16–C18, R10)

- Near the middle of the board, **away from USB-C, the buttons, the keyring
  hole and the board edges**. Board flex from plugging in or pressing a
  button shifts an MEMS sensor's zero point.
- C16/C18 at VDD (pin 9), C17 at VDD_IO (pin 10).
- LGA-12, 0.5mm pitch: 0.15mm fan-out tracks, no vias under the part.

### Pads (TP1–TP6)

- OLED pads **TP1–TP4 in a row at 2.54mm pitch in your module's pin
  order**, so wires don't cross and the header can even solder straight
  in. Check your module first: some are GND-VCC-SCL-SDA, others
  VCC-GND-…
- Silk-label every pad.
- After soldering, glue over the wires for strain relief. That's the #1
  robustness item for something on a keyring.

---

## 3. Before ordering

- [ ] DRC clean, with "unconnected items" at zero.
- [ ] Antenna rule area empty of copper on both layers (check each layer
      on its own).
- [ ] No bottom-layer trace longer than a few mm, and none under U3, X1,
      the RF trace or AE1.
- [ ] Nothing routed under X1 or next to the RF trace.
- [ ] EP has ≥9 vias. Every cap has its GND via at the pad.
- [ ] USB-C front face at the board edge.
- [ ] Silkscreen: BAT +/−, OLED pin names, RST, BOOT.
- [ ] JLC CPL rotations checked in their preview (LCSC-library footprints
      are usually right, but check the QFN, SOT-23s, LED and diode
      polarity).

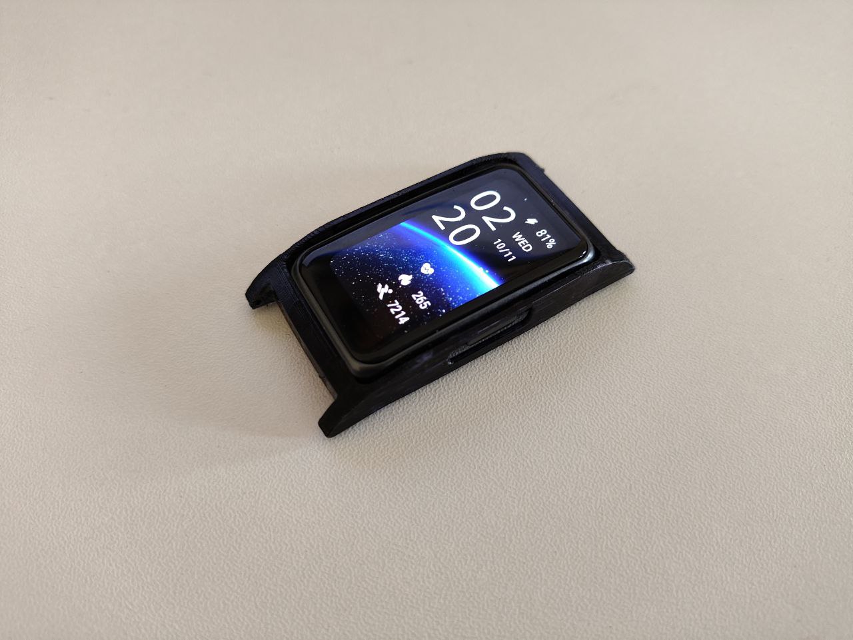
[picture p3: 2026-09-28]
22mm adapter for Huawei band 6 and Honor band 6 - 6260208/images/70614ff3-1db4-46b8-b5fa-840c29a9c139.jpg

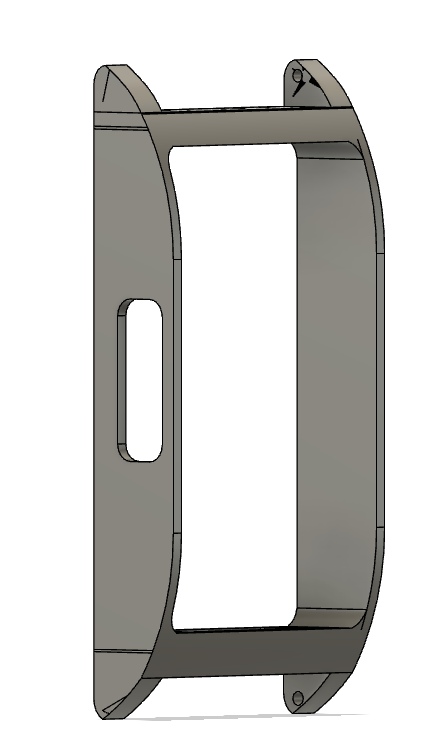
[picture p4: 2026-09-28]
22mm adapter for Huawei band 6 and Honor band 6 - 6260208/images/5cf072b8-9097-41da-a825-011a38e98a3d.png

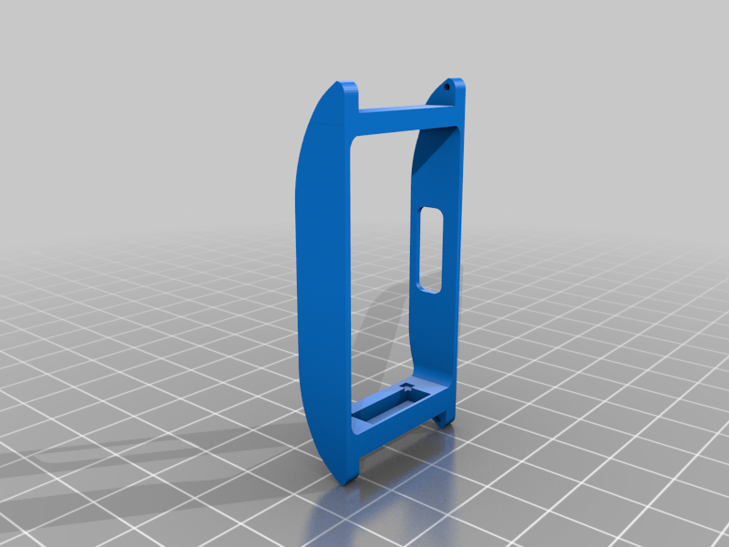
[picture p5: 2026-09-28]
22mm adapter for Huawei band 6 and Honor band 6 - 6260208/images/422cdf3e-c427-4954-85b6-9c759fb4e02e.png

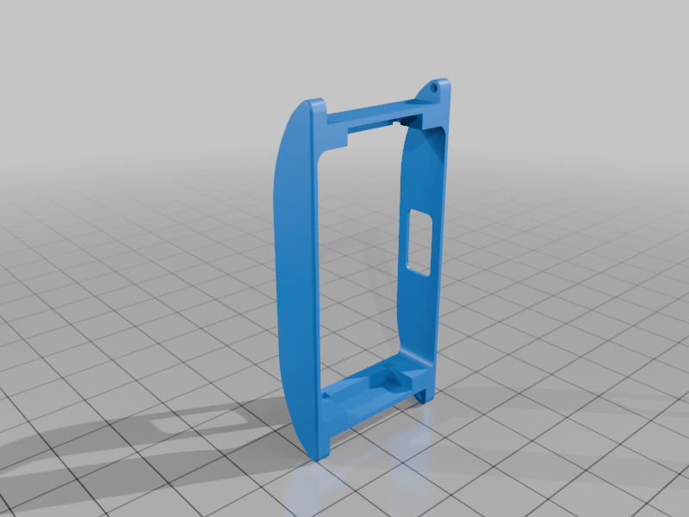
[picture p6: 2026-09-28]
22mm adapter for Huawei band 6 and Honor band 6 - 6260208/images/751f474d-0d09-409a-98de-db82b12e3467.png

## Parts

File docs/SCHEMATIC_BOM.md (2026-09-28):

# Schematic component checklist — SHAKE_FOB_REV-A

Parts + wiring, block by block. Pin names/numbers are from the actual
imported symbols. Reference designators are suggestions, renumber freely.

**Routing order:** GND (power symbol) → 3V3, VBUS, BAT, SYS (local labels) →
SDA, SCL (local labels) → Blocks 1–7 local wiring below → unused U3 pins
(12, 13, 16, 19–24, 27, 28) + USB-C SBU1/SBU2 get No-Connect flags → ERC
→ export netlist. **GPIO8 (pin 14) and GPIO3 (pin 8) are NOT No-Connect
pins.** GPIO8 needs a pull-up (Block 4c), GPIO3 is battery sense (Block 2c).

**Power nets, at a glance:** VBUS (raw 5V from USB-C) → BAT (charger output
/ the cell itself, TP5) → **SYS** (LDO input — fed from VBUS through D2 when
USB is present, from BAT through P-FET Q1 when it isn't) → 3V3 (everything
else). BAT and SYS are deliberately different nets — see Block 2.

**Ref-des / size note:** Blocks 1–2 use the schematic's real ref-des. In
Blocks 4–7, **U5 = schematic D1** (USBLC6), **ANT1 = AE1**, **Y1 = X1**,
and in 4e C14/C15 are swapped vs the schematic. Both are 1.5pF, so that
doesn't matter electrically. **All passives are 0402.** JLC Economic
PCBA only places parts down to 0402, so the last three 0201s (R1, R2, R6)
must change to 0402. See LAYOUT.md §0.

---

## Block 1 — USB-C input + ESD

Ref-des below match the actual schematic.

| Ref | Part | Value/Package | LCSC |
|---|---|---|---|
| USBC1 | TYPE-C-31-M-12 | USB-C receptacle, 16-pin | C165948 |
| R1, R2 | Resistor | 5.1 kΩ, **0402** (was 0201 C143995 — change it) | **C25905** |
| D1 | USBLC6-2SC6 | SOT23-6 | C7519 |
| C1 | Ceramic cap | 10 µF 6.3V X5R, 0402 | C15525 |
| C3 | Ceramic cap | 1 µF, 0402 | C52923 |

| Pin | → |
|---|---|
| USBC1.VBUS (both pairs) | **VBUS** net |
| USBC1.GND (both pairs) + 4× `EH` tabs | **GND** |
| USBC1.CC1 (A5) | R1 → GND |
| USBC1.CC2 (B5) | R2 → GND |
| USBC1.DP1 (A6) + DP2 (B6) | tied together → D1.pin3 |
| USBC1.DN1 (A7) + DN2 (B7) | tied together → D1.pin1 |
| C1, C3 | VBUS ↔ GND |
| D1.pin2 | GND |
| D1.pin5 | VBUS |
| D1.pin6 | → R3 → USB_D− → U3.GPIO18 (25) |
| D1.pin4 | → R4 → USB_D+ → U3.GPIO19 (26) |
| SBU1 (A8), SBU2 (B8) | No-Connect |

DP1+DP2 must be tied together, same for DN1+DN2 — connector is reversible,
skip one pair and flipped-cable orientation breaks.

---

## Block 2 — Charger + load sharing

### 2a. Charger (MCP73831)

| Ref | Part | Value/Package | LCSC |
|---|---|---|---|
| U1 | MCP73831T-2ACI/OT | SOT23-5 | C424093 |
| R5 | Resistor | 6.8 kΩ, 0402 | C25917 |
| C2 | Ceramic cap | **10 µF**, 0402 (**change from 1µF**) | C15525 |
| LED1 | LED, red | 0402 | C71911 |
| R6 | Resistor | 1 kΩ, **0402** (was 0201 C100125 — change it) | **C11702** |

| Pin | → |
|---|---|
| U1.VDD (4) | VBUS |
| U1.VSS (2) | GND |
| U1.VBAT (3) | **BAT** net → TP5, Q1 drain, R15 (2c) |
| U1.PROG (5) | R5 → GND |
| U1.STAT (1) | R6 → LED1 cathode |
| LED1 anode | VBUS |
| C2 | BAT ↔ GND |

**Charge current:** I_REG = 1000 V / R_PROG(kΩ) = 1000/6.8 = **147mA** =
0.49C for a 300mAh cell. That's a safe rate. Charger dissipation at
worst case (5V in, 3.0V cell) is 2V × 0.147A = 0.29W, fine for SOT23-5.

**C2 must be ≥4.7µF.** MCP73831 datasheet, VBAT pin: "Bypass to VSS with a
minimum of 4.7µF to ensure loop stability when the battery is
disconnected." Right now BAT has only C2 (1µF) + C4 (1µF), and C4 is moving
to SYS. Change C2 to 10µF (C15525, same part as C1/C9/C18, so no new BOM
line). A 6.3V 0402 part keeps ~4–5µF effective at 4.2V bias, which meets
the minimum.

STAT sinks (LED on) while charging and goes Hi-Z at charge-complete.
**With USB in and no battery, LED1 flickers.** The charger keeps cycling
into an empty cap, which is normal MCP73831 behavior and harmless.

### 2b. Load sharing: D2 + Q1 + R13 (Microchip AN1149)

This is the standard MCP73831 load-sharing circuit from Microchip's app
note, used on Adafruit/SparkFun LiPo boards. It covers three cases:

1. USB in, battery in → system runs from USB, battery charges alone
   (charger terminates properly instead of floating the cell at 4.2V forever
   under system load).
2. USB in, no battery → system runs from USB.
3. USB out → system runs from the battery with ~5–15mV loss.

| Ref | Part | Value/Package | LCSC | JLCPCB |
|---|---|---|---|---|
| D2 | **1N4148WS** | Si switching diode, 150mA, SOD-323 | C2128 | Basic |
| Q1 | AO3401A | P-MOSFET, −30V, R_DS(on) 85mΩ @ V_GS −2.5V, V_th −0.9V, SOT-23 | C15127 | Basic |
| R13 | Resistor | 10 kΩ, 0402 | C25744 (same as R7–R9) | Basic |

| Pin | → |
|---|---|
| D2 anode | VBUS |
| D2 cathode | **SYS** |
| Q1 pin 3 (D) | **BAT** |
| Q1 pin 2 (S) | **SYS** |
| Q1 pin 1 (G) | **VBUS** |
| R13 | VBUS ↔ GND (gate pull-down) |

After import, check that the symbol's pin names match G=1, S=2, D=3. That's
the standard SOT-23 MOSFET pinout, but wire by name, not by position.

Drain goes to the battery and source to the load. That's backwards from a
normal high-side switch, and it's on purpose: the body diode then points
BAT→SYS.

- **USB present:** SYS = VBUS − V_F(D2) ≈ 4.0–4.6V. Q1 gate = VBUS, so V_GS
  = +V_F(D2) > 0 and Q1 is always off. Body diode is reverse-biased or at
  most ~0.2V forward (BAT ≤ 4.2V), so the battery is isolated.
- **USB unplugged:** R13 pulls the gate to 0V. The body diode conducts
  first, SYS ≈ BAT − 0.6V, V_GS ≈ −3V, and Q1 turns fully on. Drop is then
  I × R_DS(on) = 170mA × 85mΩ = **14mV** worst case. D2 blocks backfeed into
  USB, and the body diode bridges the handover so the rail never drops out.
- **R13 = 10k, not 100k:** VBUS has ~5µF effective on it (C1 at 5V bias +
  C3). With 10k it decays in ~50ms after unplug, where 100k takes ~0.5s with
  the body diode carrying the load. It also holds Q1's gate low against
  D2's reverse leakage. Costs 0.5mA from USB while plugged in, and zero on
  battery.

**Why D2 is a 1N4148WS and not a Schottky.** With USB unplugged, D2 sits
reverse-biased at ~BAT voltage, and its leakage drains the battery through
R13 around the clock. Measured off the 1N5819WS (C191023) datasheet curve:
**~6–7µA at 4V/25°C, about 120µA at 100°C**. That's over half the entire
sleep budget, and it gets worse in a warm pocket. The 1N4148WS leaks in
the nA range at 4V. D2's forward drop doesn't matter: it only conducts
when USB is present, and 5V − 1V still leaves 0.7V of headroom over the
3.3V LDO. Trade-off accepted: 150mA average rating vs a load of ~40–80mA,
with short BLE peaks well inside its 2A surge rating. Same SOD-323
footprint.

**Why this replaced the D2+D3 diode-OR:** a Schottky in the battery path
(the old D3) drops ~0.25–0.35V at 50–170mA, and it drops it in the
battery-powered mode the keychain spends 99% of its time in. Q1 does the
same job for ~0.01V at zero sleep cost. BQ2407x-class power-path ICs were
rejected (QFN, +4.3µA sleep, still needs the LDO). A second LDO with a
diode-OR after regulation was rejected too: the diode would drop the 3.3V
rail itself to ~3.0V permanently.

### 2c. Battery voltage sense — recommended

| Ref | Part | Value/Package | LCSC |
|---|---|---|---|
| R15, R16 | Resistor | 1 MΩ ±1%, 0402 | C26083 (Basic) |
| C19 | Ceramic cap | 100 nF, 0402 | C1525 (same as C7) |

| Pin | → |
|---|---|
| R15 | BAT ↔ **VBAT_SENSE** |
| R16 | VBAT_SENSE ↔ GND |
| C19 | VBAT_SENSE ↔ GND |
| U3.GPIO3 (8) | VBAT_SENSE (ADC1_CH3) — **remove its No-Connect flag** |

VBAT_SENSE = BAT/2, so 4.2V reads as 2.1V, inside the ADC's 0–2500mV range
at 11dB attenuation. C19 is the charge reservoir for the ADC's sampling cap,
since a 500kΩ source can't feed it directly. Read once per wake, after the
node has settled (τ = 50ms).

**Why it's worth 2.1µA:** without it, firmware can't see the battery at
all. The LDO drops out, and the ESP32 brownout-resets every time you shake
it, until the cell's protection IC cuts at ~2.5V. That deep-discharges the
LiPo every cycle. With it, firmware refuses to wake the display below
~3.3V and can draw a battery icon. Cost is 3 small parts plus 2.1µA,
more than repaid by the ~7µA saved on D2.

---

## Block 3 — 3V3 rail (XC6206)

| Ref | Part | Value/Package | LCSC |
|---|---|---|---|
| U2 | XC6206P332MR | SOT23-3 | C5446 |
| C4, C5 | Ceramic cap | 1 µF, 0402 | C52923 |

| Pin | → |
|---|---|
| U2.Vin (3) | **SYS** (D2 cathode + Q1 source, Block 2 — not BAT directly) |
| U2.GND (1) | GND |
| U2.Vout (2) | **3V3** net |
| C4 | Vin ↔ GND (now on the SYS node) |
| C5 | Vout ↔ GND |

---

## Block 4 — ESP32-C3FH4 core

| Ref | Part | Value/Package | LCSC |
|---|---|---|---|
| U3 | ESP32-C3FH4 | QFN-32-EP 5×5mm | C2858491 |

### 4a. Power

| Pin | → |
|---|---|
| VDD3P3 (2,3) | 3V3 — C9 (10µF) + C10 (0.1µF), direct, no filter inductor (dropped — see 4d) |
| VDD3P3_RTC (11) | 3V3 — C8 (0.1µF) |
| VDD3P3_CPU (17) | 3V3 — C7 (0.1µF) |
| VDD_SPI (18) | 3V3, direct tie — C11 (1µF) |
| VDDA (31,32) | 3V3 — **C20 (1µF, C52923) + C21 (10nF, C15195) — add** |
| EP (33) | GND, ≥9 vias |

**No separate bulk cap. C9 (10µF) + C10 (0.1µF) is Espressif's own
reference value for VDD3P3.** An earlier "~650mV droop at 10µF" estimate
was wrong in two ways. It treated the full 130mA BLE peak as a step, when
the LDO is already supplying ~40mA before the burst, so the real step is
~90mA. It also assumed the LDO delivers nothing for 50µs, and nothing
backed that figure. Don't size caps off it. The real BLE-at-low-battery
risk is LDO dropout plus the 200mA limit. The Q1 fix (Block 2) and the BLE
TX-power cap (below) handle that.

**VDDA needs its own caps.** Espressif's reference schematic (hardware
design guidelines, Fig. 1) puts **1µF + 10nF on VDDA (31/32)**. An earlier
version of this doc said C9/C10 could serve VDDA by sitting "at the corner".
That doesn't work: RF pin 1 and its matching network occupy exactly the
corner between pin 32 and pin 2. Add C20 (1µF, C52923, same part as C3–C6)
and C21 (10nF, C15195, Basic) right at pins 31/32, with a GND via at each
cap.

**FIRMWARE RULES that keep the XC6206 (200mA max) in spec:**

1. **Never enable Wi-Fi.** The ESP32-C3 datasheet (Table 5-7) lists
   **335mA peak** for Wi-Fi TX at 21dBm. That's far over 200mA, and the
   rail will sag and brownout-reset. It won't cause damage, just resets.
   Watch for Arduino examples that turn Wi-Fi on by default.
2. **Cap BLE TX power** at 0dBm (`esp_ble_tx_power_set(..., ESP_PWR_LVL_N0)`
   or the NimBLE equivalent). The datasheet gives no BLE current figure, so
   the earlier "~173mA worst case" was an estimate. Measure the real peak
   with the scope and a shunt at bring-up. Range at 0dBm is plenty for a
   keychain.

The RT9013 (500mA) was rejected because its ~25µA Iq would roughly triple
the board's sleep current, while these two firmware rules cost nothing.

**Battery cutoff with the LDO** (ESP32-C3 needs ≥3.0V; XC6206 dropout is
~250mV @ 100mA, roughly proportional to current):

| Load | Old Schottky D3 | Q1 P-FET (now) |
|---|---|---|
| Active, display on, ~40–80mA | ~3.4–3.5V | **~3.1–3.2V** |
| BLE burst @ 0dBm, ~100mA | ~3.6V | **~3.3V** |

Below ~3.3V a LiPo has only a few % of its capacity left, and the cell's
protection IC cuts around 2.5–3.0V. So ~3.2V is effectively the whole
battery. Going to 2V isn't possible (ESP32-C3 minimum is 3.0V) and would
damage the cell anyway. Firmware should stop at ~3.3V using the Block 2c
sense.

### 4b. CHIP_EN

| Pin | → |
|---|---|
| CHIP_EN (7) | R7 → 3V3 · C6 → GND · SW1 → GND |

### 4c. Strapping

| Pin | → |
|---|---|
| GPIO2 (6) | R8 → 3V3 only |
| GPIO9 (15) | R9 → 3V3 · SW2 → GND · **no capacitor, ever** |
| GPIO8 (14) | **R14 (10 kΩ, 0402, C25744 — same as R7–R9) → 3V3** — remove the No-Connect flag |

**GPIO8 bug fix.** ESP32-C3 datasheet Table 3-3: Joint Download Boot needs
**GPIO8 = 1 and GPIO9 = 0**. GPIO8 has no internal pull (Table 3-1:
"Floating"). With it floating, holding BOOT + tapping RESET may not enter
download mode. That matters on this board: in deep sleep the USB-CDC port
disappears, so if firmware sleeps immediately or crashes, the BOOT button
is the only way back in. The SuperMini and Espressif dev kits hold GPIO8
high for exactly this reason. One resistor.

### 4d. Crystal

| Pin | → |
|---|---|
| XTAL_P (30) | Y1.pin1 directly — node also has C12 → GND |
| XTAL_N (29) | Y1.pin3 directly, node also has C13 → GND |
| Y1.pin2, pin4 | GND |

**L2 dropped.** Espressif lists the 24nH series inductor on XTAL_P as
harmonic-suppression margin for RF certification, not something the crystal
needs to function — their own guideline calls the value an "initial
suggestion... adjust after an overall test," i.e. it's already tunable/
optional by their own framing. Not chasing certification here, so skipped.

### 4e. RF matching — minimal: chip-side network only

**Deliberately minimal, one network not two.** Espressif's checklist
describes two possible networks (chip-side CLC and antenna-side CLC), and
the fully-by-the-book version of this design would have both. Cut back to
one for a genuinely minimal board — **kept the chip-side network, dropped
the antenna-side one.** Reasoning: a bare silicon RF pin with *no* matching
at all is typically a much larger mismatch than a purpose-built antenna's
own nominal impedance drifting somewhat from board-layout differences — so
if only one network stays, this is the one protecting against the bigger
problem. **Accepted trade-off, stated plainly**: the antenna's real
impedance on this specific board layout won't exactly match Johanson's
50Ω spec (measured on their own eval board), and that drift goes
uncorrected. For a close-range, non-certified BLE keychain, that's a
reasonable amount of range/efficiency to trade for a smaller BOM — not
"no downside," an actual accepted cost.

| Ref | Value/Package |
|---|---|
| C14 | 1.5 pF, 0402 C1552 (range 1.2–1.8 pF) |
| L3 | 2.2 nH, 0402 C27122 (range 2.0–3.0 nH) |
| C15 | 1.5 pF, 0402 C1552 (range 1.2–1.8 pF) |

Shunt-series-shunt (pi), placed close to U3: **node A: C14 → GND, and → L3**
→ **node B: C15 → GND, and → 50Ω trace straight to ANT1.pin1** — no
antenna-side network, direct connection from here.

| Pin | → |
|---|---|
| U3.LNA_IN (1) | node A (above) |
| node B (above) | 50Ω trace, direct → ANT1.pin1 (ANT, the antenna feed) |
| ANT1.pin2 | **True No-Connect** — matches Johanson's datasheet exactly, which labels this pin "NC," not GND. Mark it with a No-Connect flag in the schematic. The footprint pad is still there and still gets soldered during reflow regardless of net assignment, so the datasheet's "must be soldered for anchoring" requirement is satisfied either way — NC just means no trace/net, not no solder joint. Don't tie it to GND; that adds a connection Johanson never specified. |

Three RF-specific passives, not six. L1 and L2 are unused ref-des. C19 is
reused for the battery-sense filter cap (Block 2c).

### 4f. USB at the chip

| Pin | → |
|---|---|
| GPIO18 (25) | R3 → U5.pin1/6 (I/O1) |
| GPIO19 (26) | R4 → U5.pin3/4 (I/O2) |

Optional shunt caps + D+ pull-up footprints: unpopulated unless USB is flaky
on the bench.

### 4g. Do NOT connect

| Pins | Treatment |
|---|---|
| SPIHD/SPIWP/SPICS0/SPICLK/SPID/SPIQ (19–24) | No-Connect — reserved for in-package flash |
| U0RXD/U0TXD (27,28) | No-Connect — unused, native USB handles programming |
| MTCK/GPIO6 (12), MTDO/GPIO7 (13), GPIO10 (16) | No-Connect — spare |

---

## Block 5 — Accelerometer (MMA8452QR1)

| Ref | Part | Value/Package | LCSC |
|---|---|---|---|
| U4 | MMA8452QR1 | QFN-16 3×3mm, 0.5mm pitch, no EP | C11360 |
| C16 | Ceramic cap | 100 nF, 0402 | C1525 |
| C17 | Ceramic cap | 100 nF, 0402 | C1525 |
| C18 | Ceramic cap | 10 µF, 0402 | C15525 |

| Pin | → |
|---|---|
| U4.14 VDD | 3V3, with C16 (100nF) + C18 (10µF) right at the pin |
| U4.1 VDDIO | 3V3 (pins 1 and 14 share a corner, so tie them together there) |
| U4.2 BYP | C17 → GND. **Internal regulator output, never connect it to 3V3** |
| U4.5, U4.10, U4.12 | GND |
| U4.4 SCL | **SCL** net |
| U4.6 SDA | **SDA** net |
| U4.7 SA0 | GND → I2C address **0x1C** (OLED is 0x3C, no clash) |
| U4.11 INT1 | **INT1** net → U3.GPIO0 (pin 4), deep-sleep wake |
| U4.9 INT2 | **INT2** net → U3.GPIO1 (pin 5), spare |
| U4.3 DNC | No-Connect flag (datasheet: leave floating) |
| U4.8, 13, 15, 16 NC | No-Connect flags |

**No resistors on INT1 or INT2.** Both pins are push-pull and always
driven, never floating. After power-on they are active-low (idle high)
until firmware sets IPOL = 1.

### Firmware setup: two shakes, one transient channel

The transient detector works on high-pass-filtered data, so gravity and
slow tilting are ignored. Wake and "next gif" use the same channel on INT1,
with firmware switching the threshold. Every config write needs the chip in
**standby** (CTRL_REG1 ACTIVE = 0), with ACTIVE = 1 written last.

| Register | Asleep: vigorous shake wakes | Awake: gentle shake = next gif |
|---|---|---|
| 0x2A CTRL_REG1 | 12.5Hz → 0x28, then 0x29 | 50Hz → 0x20, then 0x21 |
| 0x2B CTRL_REG2 | low-power mode → 0x03 (**6µA**) | 0x03 |
| 0x0E XYZ_DATA_CFG | ±8g → 0x02 | 0x02 |
| 0x0F HP_FILTER_CUTOFF | 0x00 (0.25Hz cutoff) | 0x00 (1Hz cutoff) |
| 0x1D TRANSIENT_CFG | latch + X/Y/Z, HPF on → 0x1E | 0x1E |
| 0x1F TRANSIENT_THS | 1.5g → 0x18 | 0.5g → 0x08 |
| 0x20 TRANSIENT_COUNT | 3 × 80ms → 0x03 | 2 × 20ms → 0x02 |
| 0x2C CTRL_REG3 | active-high, push-pull → 0x02 | 0x02 |
| 0x2D CTRL_REG4 | transient interrupt on → 0x20 | 0x20 |
| 0x2E CTRL_REG5 | transient → INT1 → 0x20 | 0x20 |

- **Latching:** INT1 stays high until TRANSIENT_SRC (0x1E) is read, which
  suits the ESP32-C3's level wake:
  `esp_deep_sleep_enable_gpio_wakeup(BIT(0), ESP_GPIO_WAKEUP_GPIO_HIGH)`,
  with GPIO0's internal pulls disabled.
- **On wake:** read 0x1E. Wait ~0.5–1s after the last event (the wake
  shake, plus high-pass filter settling for thresholds below 1g, see NXP
  AN4071). Then load the gentle settings.
- **Before sleep:** load the wake settings, read 0x1E, then deep sleep.
- 1.5g / 0.5g and the counts are starting points. Tune them on the bench so
  walking doesn't wake the fob.
- WHO_AM_I (0x0D) reads 0x2A.

---

## Block 6 — I2C bus

| Ref | Value |
|---|---|
| R11 | 4.7 kΩ, 0402 C25900 |
| R12 | 4.7 kΩ, 0402 C25900 |

GPIO4/GPIO5 chosen for SDA/SCL (firmware config, not fixed silicon —
whatever you pick here, firmware must match).

| Pin | → |
|---|---|
| U3.pin9 (GPIO4) | **SDA**: R11 → 3V3 · U4.pin6 · TP4 |
| U3.pin10 (GPIO5) | **SCL**: R12 → 3V3 · U4.pin4 · TP3 |

---

## Block 7 — Off-board pads

| Ref | Part |
|---|---|
| TP1–TP4 | 4× bare pad, KiCad `TestPoint` lib |
| TP5–TP6 | 2× bare pad, KiCad `TestPoint` lib |

| Pad | → | Footprint |
|---|---|---|
| TP1 | GND | `TestPoint_Pad_1.5x1.5mm` |
| TP2 | 3V3 | `TestPoint_Pad_1.5x1.5mm` |
| TP3 | SCL | `TestPoint_Pad_1.5x1.5mm` |
| TP4 | SDA | `TestPoint_Pad_1.5x1.5mm` |
| TP5 | BAT (+) | `TestPoint_Pad_2.0x2.0mm` — carries charge current |
| TP6 | GND | `TestPoint_Pad_2.0x2.0mm` |

**Change the footprints.** All six are currently
`TestPoint_Pad_1.0x1.0mm`. That's too small to hand-solder a wire reliably,
and a keychain gets yanked. A 1mm pad lifts off the board the first time a
lead gets tugged. Also put a dab of hot glue or UV glue over the battery
and OLED leads as strain relief. That costs nothing and is the single
biggest robustness gain for a pocket device.

**OLED sleep current is not in the budget, so measure it.** Before deep
sleep, send the SSD1306 `0xAE` (display off) and `0x8D, 0x10` (charge pump
off) commands. **Don't** power-gate the OLED's 3V3: SDA/SCL are pulled up
to 3V3 on this board, so an unpowered OLED gets back-powered through its
I2C pins. Most 0.96" modules also carry their own small LDO and pull-ups,
so their sleep current varies by supplier. Measure yours before trusting
any battery-life number.

No connectors here — OLED and battery both arrive as bare leads from your
sources, nothing to plug in. Label every pad on silkscreen (no housing/key
to prevent a wrong wire). Verify OLED pin order against your specific module
(varies by supplier) and battery polarity against your specific pack before
soldering — both are real "confirm yourself" items, not assumed here.

---

## Not on this board

- No battery protection IC — assumes the cell has its own. Confirm.
- No physical power switch — deliberate, see README sleep-budget math.
- No 32.768kHz RTC crystal — GPIO0/GPIO1 reused as plain RTC-IO instead.

## Component count check

**56 parts** (R10 removed with the accelerometer change).

| Group | Refs | Count |
|---|---|---|
| ICs | U1–U4, D1 (USBLC6) | 5 |
| Diode / FET | D2 (1N4148WS), Q1 (AO3401A) | 2 |
| LED | LED1 | 1 |
| Resistors | R1–R9, R11–R16 | 15 |
| Capacitors | C1–C21 | 21 |
| Inductor | L3 (RF match only) | 1 |
| Crystal / antenna | X1, AE1 | 2 |
| Switches | SW1, SW2 | 2 |
| USB-C | USBC1 | 1 |
| Pads | TP1–TP6 | 6 |

All 10k resistors (R7, R8, R9, R13, R14) use **C25744** (Basic, 1%), not
C25531 (Extended, 5%).

**Sleep budget** (battery powered, everything asleep):

| Item | µA | Source |
|---|---|---|
| ESP32-C3 deep sleep | 5 | datasheet Table 5-9 |
| MMA8452Q, low-power mode, 12.5Hz | 6 | NXP datasheet Table 3 |
| XC6206 Iq | 1 | Torex |
| MCP73831 VBAT reverse leakage | 0.25 | datasheet |
| D2 leakage (1N4148WS @ 4V) | ~0.01 | was ~7 with 1N5819WS |
| Q1, R13 | 0 | VBUS = 0V |
| Battery divider R15+R16 | 2.1 | 4.2V / 2MΩ |
| **Board total** | **~14.4** | + OLED (measure) |

The cell costs something too: its protection PCB (DW01-class) draws ~3µA,
and LiPo self-discharge is ~1–2%/month (~4–8µA equivalent on 300mAh).
**Realistic standby: ~1–1.5 years**, less whatever the OLED draws. Real
life is dominated by how often it gets shaken, not by sleep current.

Run this after placing, before wiring — if what's on the canvas doesn't
roughly match, something's missing or extra.

---

## Reference — library import (already done)

9 LCSC parts imported into `ESP32_C3_FOB/libs/lcsc/` (symbol + footprint +
3D model each), registered in `sym-lib-table`/`fp-lib-table`. Reload
libraries if your editor was already open when this happened.

| Part | KiCad symbol name | KiCad footprint name |
|---|---|---|
| MCP73831T-2ACI/OT | `MCP73831T-2ACI{slash}OT` | `C424093_SOT-23-5_L3_0-W1_7-P0_95-LS2_8-BL` |
| XC6206P332MR | `XC6206P332MR` | `C5446_SOT-23-3_L2_9-W1_6-P1_90-LS2_8-BR` |
| ESP32-C3FH4 | `ESP32-C3FH4` | `C2858491_QFN-32_L5_0-W5_0-P0_50-TL-EP3_7` |
| MMA8452QR1 | import C11360 with the LCSC plugin | as generated by the import |
| USBLC6-2SC6 | `USBLC6-2SC6` | `C7519_SOT-23-6_L2_9-W1_6-P0_95-LS2_8-BL` |
| Crystal 40MHz | `3225_40M_12PF_10PPM` | `C5380316_CRYSTAL-SMD_4P-L3_2-W2_5-BL` |
| Johanson antenna | `Mini_2_45_GHz_Antenna,_Johanson_Technology` | `C89334_ANT-SMD_L3_2-W1_6` |
| Tactile switch | `TS342A2P` | `C398055_SW-SMD_L4_0-W3_0-LS5_0-EH` |
| USB-C receptacle | `TYPE-C-31-M-12` | `C165948_USB-C_SMD-TYPE-C-31-M-12_1` |

Note: C13738 (originally picked for the crystal) was a 16MHz part, wrong —
swapped for C5380316 (40MHz, confirmed), deleted from the library rather
than left in. S2B-PH-SM4-TB / C295747 (battery connector) was also
imported, then dropped — board uses solder pads instead (Block 7).

Generic parts (KiCad built-in `Device`/`TestPoint` libs, no import): all R/C/L,
D1, TP1–6.

**Packages:** every passive is **0402**. JLC Economic PCBA's minimum is
0402, and a single 0201 forces Standard PCBA (≥70×70mm board or a railed
panel, plus a higher fee). The earlier 0201 plan was dropped for that reason.

## Reference — verified against Espressif's live checklist

Checked every value in this document against
[docs.espressif.com's schematic checklist](https://docs.espressif.com/projects/esp-hardware-design-guidelines/en/latest/esp32c3/schematic-checklist.html)
directly — all matched except the crystal load-cap formula (PDF extraction
had garbled it; corrected: `C_L=(C1×C2)/(C1+C2)+C_stray` → C1=C2=18pF). One
item on their checklist not here: 499Ω on U0TXD — skipped, UART0 unused.

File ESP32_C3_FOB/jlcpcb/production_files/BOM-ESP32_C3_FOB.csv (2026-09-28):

Comment | Designator | Footprint | LCSC | Quantity
1.5pF | C14,C15 | C1552_C0402 | C1552 | 2
100nF | C10,C16,C17,C7,C8 | C1525_C0402 | C1525 | 5
10K | R13,R14,R7,R8,R9 | C25744_R0402 | C25744 | 5
10nF | C21 | C15195_C0402 | C15195 | 1
10uF | C1,C18,C2,C9 | C15525_C0402 | C15525 | 4
18pF | C12,C13 | C1549_C0402 | C1549 | 2
1N4148WS T4 | D2 | C2128_SOD-323_L1_8-W1_3-LS2_5-RD | C2128 | 1
1k | R6 | C11702_R0402 | C11702 | 1
1uF | C11,C20,C3,C4,C5,C6 | C52923_C0402 | C52923 | 6
2.2nH | L3 | C27122_L0402 | C27122 | 1
2.45 GHz | AE1 | C89334_ANT-SMD_L3_2-W1_6 | C89334 | 1
22Ω (22R0) ±1% | R3,R4 | C25092_R0402 | C25092 | 2
3225 40M 12PF 10PPM | X1 | C5380316_CRYSTAL-SMD_4P-L3_2-W2_5-BL | C5380316 | 1
4.7K | R11,R12 | C25900_R0402 | C25900 | 2
5.1k | R1,R2 | C25905_R0402 | C25905 | 2
6.8K | R5 | C25917_R0402 | C25917 | 1
AO3401A | Q1 | C15127_SOT-23_L2_9-W1_3-P1_90-LS2_4-BR | C15127 | 1
ESP32-C3FH4 | U3 | C2858491_QFN-32_L5_0-W5_0-P0_50-TL-EP3_7 | C2858491 | 1
LED 0402 | LED1 | C71911_LED0402-R-RD | C71911 | 1
MCP73831T-2ACI/OT | U1 | C424093_SOT-23-5_L3_0-W1_7-P0_95-LS2_8-BL | C424093 | 1
MMA8452QR1_C11360 | U4 | C11360_QFN-16_L3_0-W3_0-P0_50-TL_MMA8452QR1 | C11360 | 1
TS342A2P | SW1,SW2 | C398055_SW-SMD_L4_0-W3_0-LS5_0-EH | C398055 | 2
TYPE-C | USBC1 | C165948_USB-C_SMD-TYPE-C-31-M-12_1 | C165948 | 1
USBLC6-2SC6 | D1 | C7519_SOT-23-6_L2_9-W1_6-P0_95-LS2_8-BL | C7519 | 1
XC6206P332MR | U2 | C5446_SOT-23-3_L2_9-W1_6-P1_90-LS2_8-BR | C5446 | 1

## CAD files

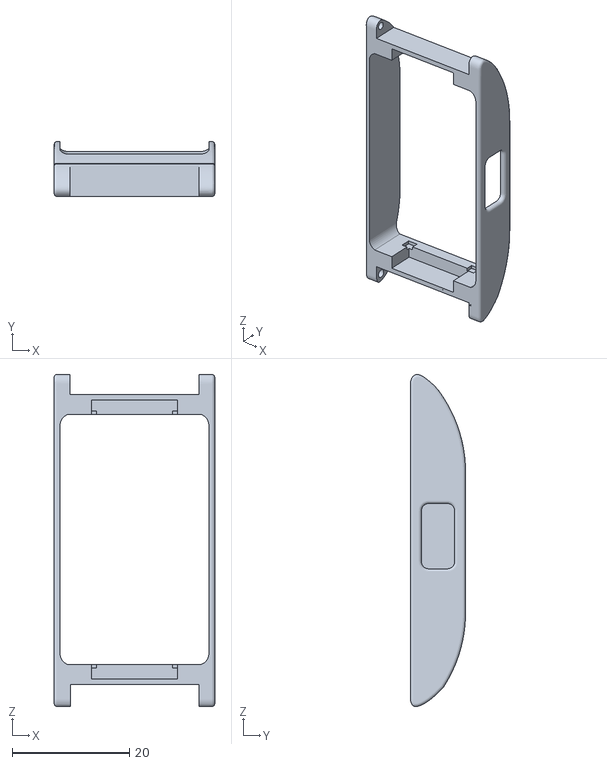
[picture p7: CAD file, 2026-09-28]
22mm adapter for Huawei band 6 and Honor band 6 - 6260208/files/22mm_adaptor_for_huawei_band_6_v13.stl
27.4 x 9.40 x 56.6

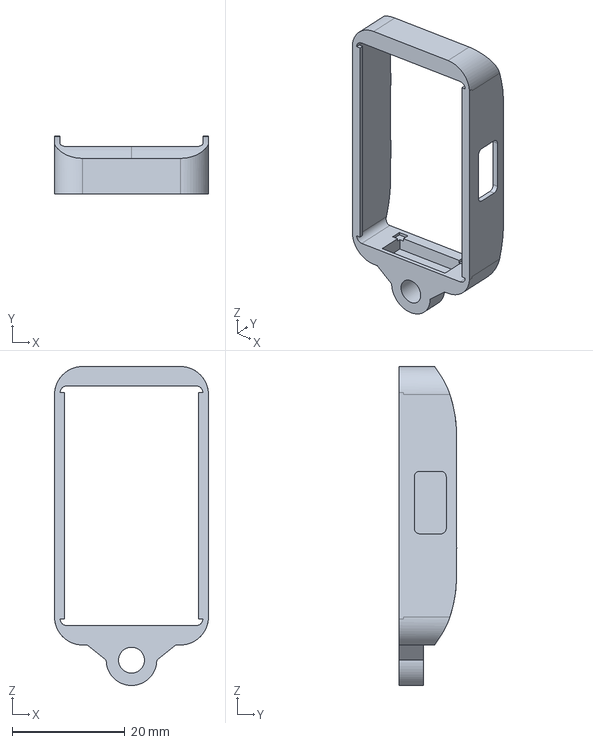
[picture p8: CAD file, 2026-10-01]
keychain_case/band6_keychain_case.step
27.4 x 10.2 x 56.7 mm

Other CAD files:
keychain_case/band6_keychain_case.stl

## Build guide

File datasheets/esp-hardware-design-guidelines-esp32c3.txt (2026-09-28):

===PAGE 1===
ESP32-C3
Hardware Design Guidelines
Releasemaster
EspressifSystems
Sep17,2026
===PAGE 2===
Table of contents
Table of contents i
1 Latest Version of This Document 3
1.1 AboutThisDocument . . . . . . . . . . . . . . . . . . . . . . . . . . . . . . . . . . . . . . . .3
1.1.1 Introduction . . . . . . . . . . . . . . . . . . . . . . . . . . . . . . . . . . . . . . . . .3
1.1.2 LatestVersionofThisDocument . . . . . . . . . . . . . . . . . . . . . . . . . . . . . .3
1.2 ProductOverview . . . . . . . . . . . . . . . . . . . . . . . . . . . . . . . . . . . . . . . . . . .3
1.3 SchematicChecklist . . . . . . . . . . . . . . . . . . . . . . . . . . . . . . . . . . . . . . . . .4
1.3.1 Overview . . . . . . . . . . . . . . . . . . . . . . . . . . . . . . . . . . . . . . . . . .4
1.3.2 PowerSupply . . . . . . . . . . . . . . . . . . . . . . . . . . . . . . . . . . . . . . . .5
1.3.3 ChipPower-upandResetTiming . . . . . . . . . . . . . . . . . . . . . . . . . . . . . .6
1.3.4 Flash . . . . . . . . . . . . . . . . . . . . . . . . . . . . . . . . . . . . . . . . . . . . .7
1.3.5 ClockSource . . . . . . . . . . . . . . . . . . . . . . . . . . . . . . . . . . . . . . . .7
1.3.6 RF . . . . . . . . . . . . . . . . . . . . . . . . . . . . . . . . . . . . . . . . . . . . . .9
1.3.7 UART . . . . . . . . . . . . . . . . . . . . . . . . . . . . . . . . . . . . . . . . . . . .11
1.3.8 SPI . . . . . . . . . . . . . . . . . . . . . . . . . . . . . . . . . . . . . . . . . . . . .11
1.3.9 StrappingPins . . . . . . . . . . . . . . . . . . . . . . . . . . . . . . . . . . . . . . . .11
1.3.10 GPIO . . . . . . . . . . . . . . . . . . . . . . . . . . . . . . . . . . . . . . . . . . . .13
1.3.11 ADC . . . . . . . . . . . . . . . . . . . . . . . . . . . . . . . . . . . . . . . . . . . . .14
1.3.12 USB . . . . . . . . . . . . . . . . . . . . . . . . . . . . . . . . . . . . . . . . . . . . .14
1.4 PCBLayoutDesign . . . . . . . . . . . . . . . . . . . . . . . . . . . . . . . . . . . . . . . . . .15
1.4.1 GeneralPrinciplesofPCBLayoutfortheChip . . . . . . . . . . . . . . . . . . . . . . .15
1.4.2 PowerSupply . . . . . . . . . . . . . . . . . . . . . . . . . . . . . . . . . . . . . . . .15
1.4.3 Crystal . . . . . . . . . . . . . . . . . . . . . . . . . . . . . . . . . . . . . . . . . . . .17
1.4.4 RF . . . . . . . . . . . . . . . . . . . . . . . . . . . . . . . . . . . . . . . . . . . . . .18
1.4.5 Flash . . . . . . . . . . . . . . . . . . . . . . . . . . . . . . . . . . . . . . . . . . . . .19
1.4.6 UART . . . . . . . . . . . . . . . . . . . . . . . . . . . . . . . . . . . . . . . . . . . .20
1.4.7 GeneralPrinciplesofPCBLayoutforModules(PositioningaModuleonaBaseBoard) . 21
1.4.8 USB . . . . . . . . . . . . . . . . . . . . . . . . . . . . . . . . . . . . . . . . . . . . .22
1.4.9 TypicalLayoutProblemsandSolutions . . . . . . . . . . . . . . . . . . . . . . . . . . .22
1.5 DownloadGuidelines . . . . . . . . . . . . . . . . . . . . . . . . . . . . . . . . . . . . . . . . .23
1.6 RelatedDocumentationandResources . . . . . . . . . . . . . . . . . . . . . . . . . . . . . . . .24
1.6.1 ESP32-C3Modules . . . . . . . . . . . . . . . . . . . . . . . . . . . . . . . . . . . . .24
1.6.2 ESP32-C3DevelopmentBoards . . . . . . . . . . . . . . . . . . . . . . . . . . . . . .25
1.6.3 OtherRelatedDocumentationandResources . . . . . . . . . . . . . . . . . . . . . . . .25
1.7 Glossary . . . . . . . . . . . . . . . . . . . . . . . . . . . . . . . . . . . . . . . . . . . . . . .25
1.8 RevisionHistory . . . . . . . . . . . . . . . . . . . . . . . . . . . . . . . . . . . . . . . . . . .26
1.9 DisclaimerandCopyrightNotice . . . . . . . . . . . . . . . . . . . . . . . . . . . . . . . . . . .27
1.9.1 TermsofUseforReferenceDesigns . . . . . . . . . . . . . . . . . . . . . . . . . . . .28
i
===PAGE 3===
ii
===PAGE 4===
Tableofcontents
Thisdocumentprovidesguidelinesforthe ESP32-C3SoC.
SchematicChecklist PCBLayoutDesign DownloadGuidelines Resources
EspressifSystems 1
Submit Document Feedback
Releasemaster
===PAGE 5===
Tableofcontents
EspressifSystems 2
Submit Document Feedback
Releasemaster
===PAGE 6===
Chapter 1
Latest Version of This Document
Check the link to make sure that you use the latest version of this document:https://docs.espressif.com/projects/
esp-hardware-design-guidelines/en/latest/esp32c3/index.html
1.1 About This Document
1.1.1 Introduction
The hardware design guidelines advise on how to integrate ESP32-C3 into a product. These guidelines will help to
achieveoptimalperformanceofyourproduct,ensuringtechnicalaccuracyandadherencetoEspressif nsstandards.
Theguidelinesareintendedforhardwareandapplicationengineers.
ThedocumentassumesthatyoupossessacertainleveloffamiliaritywiththeESP32-C3SoC.Incaseyoulackprior
knowledge,werecommendutilizingthisdocumentinconjunctionwiththe ESP32-C3SeriesDatasheet .
1.1.2 Latest Version of This Document
Check the link to make sure that you use the latest version of this document:https://docs.espressif.com/projects/
esp-hardware-design-guidelines/en/latest/esp32c3/index.html
1.2 Product Overview
ESP32-C3isasystemonachipthatintegratesthefollowingfeatures:
• Wi-Fi(2.4GHzband)
• Bluetooth®5(LE)
• Highperformance32-bitRISC-Vsingle-coreprocessor
• Multipleperipherals
• Built-insecurityhardware
Poweredby40nmtechnology,ESP32-C3providesarobust, highly-integratedplatform,whichhelpsmeetthecon-
tinuous demands for efficient power usage, compact design, security, high performance, and reliability. Typical
applicationscenariosforESP32-C3include:
• SmartHome
3
===PAGE 7===
Chapter1. LatestVersionofThisDocument
• IndustrialAutomation
• HealthCare
• ConsumerElectronics
• SmartAgriculture
• POSMachines
• ServiceRobot
• AudioDevices
• GenericLow-powerIoTSensorHubs
• GenericLow-powerIoTDataLoggers
FormoreinformationaboutESP32-C3,pleasereferto ESP32-C3SeriesDatasheet .
Note: Unless otherwise specified,oESP32-C3pused in this document refers to the series of chips, instead of a
specificchipvariant.
1.3 Schematic Checklist
1.3.1 Overview
The integrated circuitry of ESP32-C3 requires only 20 electrical components (resistors, capacitors, and inductors)
andacrystal,aswellasanSPIflash. ThehighintegrationofESP32-C3allowsforsimpleperipheralcircuitdesign.
ThischapterdetailstheschematicdesignofESP32-C3.
ThefollowingfigureshowsareferenceschematicdesignofESP32-C3. Itcanbeusedasthebasisofyourschematic
design.
Fig.1: ESP32-C3ReferenceSchematic
EspressifSystems 4
Submit Document Feedback
Releasemaster
===PAGE 8===
Chapter1. LatestVersionofThisDocument
AnybasicESP32-C3circuitdesignmaybebrokendownintothefollowingmajorbuildingblocks:
• Power supply
• Chip power-up and reset timing
• Flash
• Clock source
• RF
• UART
• SPI
• Strapping pins
• GPIO
• ADC
• USB
Therestofthischapterdetailsthespecificsofcircuitdesignforeachofthesesections.
1.3.2 Power Supply
Thegeneralrecommendationsforpowersupplydesignare:
• When using a single power supply, the recommended power supply voltageis 3.3 V and the outputcurrent is
nolessthan500mA.
• ItissuggestedtoaddanESDprotectiondiodeandatleast10μFcapacitoratthemainpowerentrance(where
theexternalpowersupplyentersthePCB).
Thepowerschemeisshownin ESP32-C3SeriesDatasheet >Figure ESP32-C3 Power Scheme.
Moreinformationaboutpowersupplypinscanbefoundin ESP32-C3SeriesDatasheet >Section Power Supply.
Digital Power Supply
ESP32-C3haspin17VDD3P3_CPUasthedigitalpowersupplypin(s)workinginavoltagerangeof3.0V~3.6V.
Itisrecommendedtoaddanextra0.1μFdecouplingcapacitorclosetothepin(s).
Pin VDD_SPI can serve as the power supply for the external device at 3.3 V (typical value), provided by
VDD3P3_CPU via RSPI. Therefore, there will be some voltage drop from VDD3P3_CPU. When the VDD_SPI
outputs3.3V,itisrecommendedthatusersadda1μFcapacitorclosetoVDD_SPI.
VDD_SPIcanbeconnectedtoandpoweredbyanexternalpowersupply.
Whennotservingasapowersupplypin,VDD_SPIcanbeusedasaregularGPIO.
Attention: When usingVDD_SPI as the powersupplypinforthe in-packageflashorexternal 3.3 V flash, the
supply voltage should be 3.0 V or above, so as to meet the requirements of flashns working voltage. In such
cases,VDD_SPIcannotbeusedasaregularGPIO.
Analog Power Supply
ESP32-C3nsVDDAandVDD3P3pinsaretheanalogpowersupplypins,workingat3.0V~3.6V.
For VDD3P3, when ESP32-C3 is transmitting signals, there may be a sudden increase in the current draw, causing
powerrailcollapse. Therefore,itishighlyrecommendedtoadda10μFcapacitortothepowerrail,whichcanwork
inconjunctionwiththe0.1μFcapacitor(s)orothercapacitors.
It is suggested to add an extra 10 μF capacitor at the main power entrance. If the main power entrance is close to
VDD3P3,thenthetwo10μFcapacitorscanbemergedintoone.
EspressifSystems 5
Submit Document Feedback
Releasemaster
===PAGE 9===
Chapter1. LatestVersionofThisDocument
AddanLCcircuittotheVDD3P3powerrailtosuppresshigh-frequencyharmonics. Theinductor nsratedcurrent
ispreferably500mAandabove.
Fortheremainingcapacitorcircuits,pleasereferto ESP32-C3 Reference Schematic.
RTC Power Supply
ESP32-C3nsVDD3P3_RTCpinistheRTCandanalogpowerpin. Itisrecommendedtoplacea0.1μFdecoupling
capacitornearthispowerpininthecircuit.
Notethatthispowersupplycannotbeusedasasinglebackuppowersupply.
TheschematicfortheRTCpowersupplypinisshowninFigure ESP32-C3 Schematic for RTC Power Supply Pin.
Fig.2: ESP32-C3SchematicforRTCPowerSupplyPin
1.3.3 Chip Power-up and Reset Timing
ESP32-C3nsCHIP_ENpincanenablethechipwhenitishighandresetthechipwhenitislow.
When ESP32-C3 uses a 3.3 V system power supply, the power rails need some time to stabilize before CHIP_EN
ispulledupandthechipisenabled. Therefore, CHIP_ENneedstobeassertedhighafterthe3.3Vrailshavebeen
broughtup.
To reset the chip, keep the reset voltage VIL_nRST in the range of (⚶0.3 ~ 0.25 × VDD) V. To avoid reboots caused
byexternalinterferences,maketheCHIP_ENtraceasshortaspossible.
Figure ESP32-C3 Power-up and Reset Timing showsthepower-upandresettimingofESP32-C3.
Fig.3: ESP32-C3Power-upandResetTiming
Table Description of Timing Parameters for Power-up and Reset providesthespecifictimingrequirements.
EspressifSystems 6
Submit Document Feedback
Releasemaster
===PAGE 10===
Chapter1. LatestVersionofThisDocument
Table1: DescriptionofTimingParametersforPower-upandReset
Parameter Description Minimum (µs)
tSTBL TimereservedforthepowerrailstostabilizebeforetheCHIP_EN
pinispulledhightoactivatethechip
50
tRST Time reserved for CHIP_EN to stay below VIL_nRST to reset the
chip
50
Attention:
• CHIP_ENmustnotbeleftfloating.
• Toensurethecorrectpower-upandresettiming,itisadvisedtoaddanRCdelaycircuitattheCHIP_EN
pin. TherecommendedsettingfortheRCdelaycircuitisusuallyR=10kΩandC=1μF.However,specific
parameters should be adjusted based on the characteristics of the actual power supply and the power-up
andresettimingofthechip.
• Iftheuserapplicationhasoneofthefollowingscenarios:
– Slowpowerriseorfall,suchasduringbatterycharging.
– Frequentpoweron/offoperations.
– Unstablepowersupply,suchasinphotovoltaicpowergeneration.
Then,theRCcircuitalonemaynotmeetthetimingrequirements,whichmaypreventthechipfromentering
normaloperatingmodeorcauseflasheraseoperationstooccasionallyfailtocomplete. Inthiscase,please
reserveapowermonitorchiptoresetthechipwhenthepowersupplyisabnormal,andthethresholdofthe
powermonitorchipisrecommendedtobearound3.0V.
1.3.4 Flash
ESP32-C3cansupportupto16MBexternalflash,poweredbyVDD_SPI.Itisrecommendedtoaddzero-ohmresistor
footprints in series on the SPI communication lines as shown in FigureESP32-C3 Schematic for External Flash .
Thesefootprintsprovideflexibilityforfutureadjustments,suchastuningdrivestrength,mitigatingRFinterference,
correctingsignaltiming,andreducingnoise,ifneeded.
FortheESP32-C3variantswithin-packageSPIflash,thepinsforflashcommunicationcannotbeusedexternallyfor
otherpurposes.
Fig.4: ESP32-C3SchematicforExternalFlash
1.3.5 Clock Source
ESP32-C3supportstwoexternalclocksources:
EspressifSystems 7
Submit Document Feedback
Releasemaster
===PAGE 11===
Chapter1. LatestVersionofThisDocument
• External crystal clock source (Compulsory)
• RTC clock source (Optional)
External Crystal Clock Source (Compulsory)
TheESP32-C3firmwareonlysupports40MHzcrystal.
ThecircuitforthecrystalisshowninFigure ESP32-C3 Schematic for External Crystal. Notethattheaccuracyofthe
selectedcrystalshouldbewithin±10ppm.
Fig.5: ESP32-C3SchematicforExternalCrystal
Please add a series component on the XTAL_P clock trace. Initially, it is suggested to use an inductor of 24 nH to
reducetheimpactofhigh-frequencycrystalharmonicsonRFperformance,andthevalueshouldbeadjustedafteran
overalltest.
TheinitialvaluesofexternalcapacitorsC1andC2canbedeterminedaccordingtotheformula:
CL = C1 × C2
C1 + C2 + Cstray
wherethevalueofC L(loadcapacitance)canbefoundinthecrystal nsdatasheet,andthevalueofC strayreferstothe
PCBnsstraycapacitance. ThevaluesofC1andC2needtobefurtheradjustedafteranoveralltestasbelow:
1. SelectTXtonemodeusingthe CertificationandTestTool .
2. Observethe2.4GHzsignalwitharadiocommunicationanalyzeroraspectrumanalyzeranddemodulateitto
obtaintheactualfrequencyoffset.
3. Adjustthefrequencyoffsettobewithin±10ppm(recommended)byadjustingtheexternalloadcapacitance.
• When the center frequency offset is positive, it means that the equivalent load capacitance is small, and the
externalloadcapacitanceneedstobeincreased.
• Whenthecenterfrequencyoffsetisnegative,itmeanstheequivalentloadcapacitanceislarge,andtheexternal
loadcapacitanceneedstobereduced.
• Externalloadcapacitanceatthetwosidesareusuallyequal,butinspecialcases,theymayhaveslightlydifferent
values.
Note:
• Defectsinthemanufacturingofcrystal(forexample,largefrequencydeviationofmorethan±10ppm,unstable
performancewithintheoperatingtemperaturerange,etc)mayleadtothemalfunctionofESP32-C3,resulting
inadecreaseoftheRFperformance.
• Itisrecommendedthattheamplitudeofthecrystalisgreaterthan500mV.
• WhenWi-FiorBluetoothconnectionfails,afterrulingoutsoftwareproblems,youmayfollowthestepsmen-
tionedabovetoensurethatthefrequencyoffsetmeetstherequirementsbyadjustingcapacitorsatthetwosides
ofthecrystal.
EspressifSystems 8
Submit Document Feedback
Releasemaster
===PAGE 12===
Chapter1. LatestVersionofThisDocument
RTC Clock Source (Optional)
ESP32-C3supportsanexternal32.768kHzcrystaltoactastheRTCclock. TheexternalRTCclocksourceenhances
timingaccuracyandconsequentlydecreasesaveragepowerconsumption,withoutimpactingfunctionality.
Figure ESP32-C3 Schematic for 32.768 kHz Crystal showstheschematicfortheexternal32.768kHzcrystal.
Fig.6: ESP32-C3Schematicfor32.768kHzCrystal
Pleasenotetherequirementsforthe32.768kHzcrystal:
• Equivalentseriesresistance(ESR)≤70kΩ.
• Loadcapacitanceatbothendsshouldbeconfiguredaccordingtothecrystal nsspecification.
TheparallelresistorRisusedforbiasingthecrystalcircuit(5MΩ<R≤10MΩ).
Ingeneral,youdonotneedtopopulatetheresistor.
IftheRTCclocksourceisnotrequired,thenthepinsforthe32.768kHzcrystalcanbeusedasGPIOs.
1.3.6 RF
RF Circuit
ESP32-C3ns RF circuit is mainly composed of three parts, the RF traces on the PCB board, the chip matching
circuit,theantennaandtheantennamatchingcircuit. Eachpartshouldmeetthefollowingrequirements:
• FortheRFtracesonthePCBboard,50Ωimpedancecontrolisrequired.
• Forthechipmatchingcircuit,itmustbeplacedclosetothechip. ACLCstructureispreferred.
– TheCLCstructureismainlyusedtoadjusttheimpedancepointandsuppressharmonics,and
asetofLCcanbeaddedifspacepermits.
– TheRFmatchingcircuitisshowninFigure ESP32-C3 Schematic for RF Matching.
• Fortheantennaandtheantennamatchingcircuit,toensureradiationperformance,theantenna nscharacteristic
impedancemustbearound50Ω.AddingaCLCmatchingcircuitneartheantennaisrecommendedtoadjust
theantenna. However,iftheavailablespaceislimitedandtheantennaimpedancepointcanbeguaranteedto
be50Ωbysimulation,thenthereisnoneedtoaddamatchingcircuitneartheantenna.
RF Tuning
TheRFmatchingparametersvarywiththeboard,sotheonesusedinEspressifmodulescouldnotbeapplieddirectly.
FollowtheinstructionsbelowtodoRFtuning.
Figure ESP32-C3 RF Tuning Diagram showsthegeneralprocessofRFtuning.
Inthematchingcircuit,definetheportnearthechipasPort1andtheportneartheantennaasPort2. S11describes
the ratio of the signal power reflected back from Port 1 to the input signal power, the transmission performance is
bestifthematchingimpedanceisconjugatetothechipimpedance. S21isusedtodescribethetransmissionlossof
EspressifSystems 9
Submit Document Feedback
Releasemaster
===PAGE 13===
Chapter1. LatestVersionofThisDocument
Fig.7: ESP32-C3SchematicforRFMatching
Fig.8: ESP32-C3RFTuningDiagram
EspressifSystems 10
Submit Document Feedback
Releasemaster
===PAGE 14===
Chapter1. LatestVersionofThisDocument
signalfromPort1toPort2. IfS11isclosetothechipconjugatepoint35+j0andS21islessthan-35dBat4.8GHz
and7.2GHz,thematchingcircuitcansatisfytransmissionrequirements.
Connect the two ends of the matching circuit to the network analyzer, and test its signal reflection parameter S11
and transmission parameter S21. Adjust the values of the components in the circuit until S11 and S21 meet the
requirements. IfyourPCBdesignofthechipstrictlyfollowsthePCBdesignstatedinChapter PCB Layout Design,
youcanrefertothevaluerangesinTable Recommended Value Ranges for Componentstodebugthematchingcircuit.
Table2: RecommendedValueRangesforComponents
Reference Desig-
nator
Recommended Value Range Serial No.
C11 1.2~1.8pF GRM0335C1H1RXBA01D
L2 2.0~3.0nH LQP03TN2NXB02D
C12 1.8~1.2pF GRM0335C1H1RXBA01D
Please use 0201 packages for RF matching components and add a stub to the first capacitor in the matching circuit
atthechipend.
Note: If RF function is not required, it is recommended not to initialize the RF stack in firmware. In this case,
the RF pin can be left floating. However, if RF function is enabled, make sure an antenna is connected. Operation
withoutanantennamayresultinunstablebehaviororpotentialdamagetotheRFcircuit.
1.3.7 UART
Usually,UART0isusedastheserialportfordownloadandlogprinting. ForinstructionsondownloadoverUART0,
please refer to SectionDownload Guidelines. It is recommended to connect a 499 Ω series resistor to the U0TXD
linetosuppressharmonics.
Forapplicationcommunication,useUARTinterfacesotherthanUART0ifpossible. AddaseriesresistorontheTX
linetosuppressharmonics.
WhenusingtheATfirmware,pleasenotethattheUARTGPIOisalreadyconfigured(referto HardwareConnection).
Itisrecommendedtousethedefaultconfiguration.
1.3.8 SPI
When using the SPI function, to improve EMC performance, add a series resistor (or ferrite bead) and a capacitor
to ground on the SPI_CLK trace. If space allows, it is recommended to also add a series resistor and capacitor to
groundonotherSPItraces. EnsurethattheRC/LCcomponentsareplacedclosetothepinsofthechipormodule.
1.3.9 Strapping Pins
At each startup or reset, a chip requires some initial configuration parameters, such as in which boot mode to load
thechip,etc. Theseparametersarepassedoverviathestrappingpins. Afterreset,thestrappingpinsworkasnormal
functionpins.
GPIO2,GPIO8,andGPIO9arestrappingpins.
Alltheinformationaboutstrappingpinsiscoveredin ESP32-C3SeriesDatasheet >Chapter Boot Configurations.
Inthissection,wewillmainlycoverthestrappingpinsrelatedtobootmode.
Afterchipresetisreleased,thecombinationofGPIO2,GPIO8,andGPIO9controlsthebootmode. SeeTable Boot
Mode Control.
EspressifSystems 11
Submit Document Feedback
Releasemaster
===PAGE 15===
Chapter1. LatestVersionofThisDocument
Table3: BootModeControl
Boot Mode GPIO2Page12,1 GPIO8 GPIO9
DefaultConfig ⚶(Floating) ⚶(Floating) 1(Pull-up)
SPIBoot(default) 1 Anyvalue 1
JointDownloadBoot 2 1 1 0
Signalsappliedtothestrappingpinsshouldhavespecific setup time and hold time. Formoreinformation,seeFigure
Setup and Hold Times for Strapping Pins andTable Description of Timing Parameters for Strapping Pins.
Fig.9: SetupandHoldTimesforStrappingPins
Table4: DescriptionofTimingParametersforStrappingPins
Parameter Description Minimum (ms)
tSU Timereservedforthepowerrailstostabilizebeforethechipenable
pin(CHIP_EN)ispulledhightoactivatethechip.
0
tH Time reserved for the chip to read the strapping pin values after
CHIP_EN is already high and before these pins start operating as
regularIOpins.
3
Attention:
• Itisrecommendedtoplaceapull-upresistorattheGPIO9pin.
• Donotaddhigh-valuecapacitorsatGPIO9,orthechipmayenterdownloadmode.
1 GPIO2actuallydoesnotdetermineSPIBootandJointDownloadBootmode,butitisrecommendedtopullthispinupduetoglitches.
2 JointDownloadBootmodesupportsthefollowingdownloadmethods:
• USB-Serial-JTAGDownloadBoot
• UARTDownloadBoot
EspressifSystems 12
Submit Document Feedback
Releasemaster
===PAGE 16===
Chapter1. LatestVersionofThisDocument
1.3.10 GPIO
ThepinsofESP32-C3canbeconfiguredviaIOMUXorGPIOmatrix. IOMUXprovidesthedefaultpinconfigura-
tions(see ESP32-C3SeriesDatasheet >Appendix ESP32-C3 Consolidated Pin Overview),whereastheGPIOmatrix
is used to route signals from peripherals to GPIO pins. For more information about IO MUX and GPIO matrix,
pleasereferto ESP32-C3TechnicalReferenceManual >Chapter IO MUX and GPIO Matrix.
Some peripheral signals have already been routed to certain GPIO pins, while some can be routed to any available
GPIOpins. Fordetails,pleasereferto ESP32-C3SeriesDatasheet >Section Peripherals.
WhenusingGPIOs,please:
• Payattentiontothestatesofstrappingpinsduringpower-up.
• PayattentiontothedefaultGPIOconfigurationsafterreset(seethetablebelow). Forunusedpinsinthehigh-
impedance state without an internal pull-up or pull-down, it is recommended to add a pull-up or pull-down
resistor or enable the internal pull during software initialization to avoid extra power consumption, selecting
thedirectionasrequiredbytheexternalcircuit.
• Avoidusingthepinsalreadyoccupiedbyflash.
• Somepinswillhaveglitchesduringpower-up. RefertoTable Power-Up Glitches on Pins fordetails.
Table5: IOMUXPinFunctions
Name No. Function 0 Function 1 Function 2 Reset Notes
XTAL_32K_P 4 GPIO0 GPIO0 i 0 R
XTAL_32K_N 5 GPIO1 GPIO1 i 0 R
GPIO2 6 GPIO2 GPIO2 FSPIQ 1 R
GPIO3 8 GPIO3 GPIO3 i 1 R
MTMS 9 MTMS GPIO4 FSPIHD 1 R
MTDI 10 MTDI GPIO5 FSPIWP 1 R
MTCK 12 MTCK GPIO6 FSPICLK 1* G
MTDO 13 MTDO GPIO7 FSPID 1 G
GPIO8 14 GPIO8 GPIO8 i 1 i
GPIO9 15 GPIO9 GPIO9 i 3 i
GPIO10 16 GPIO10 GPIO10 FSPICS0 1 G
VDD_SPI 18 GPIO11 GPIO11 i 0 i
SPIHD 19 SPIHD GPIO12 i 3 i
SPIWP 20 SPIWP GPIO13 i 3 i
SPICS0 21 SPICS0 GPIO14 i 3 i
SPICLK 22 SPICLK GPIO15 i 3 i
SPID 23 SPID GPIO16 i 3 i
SPIQ 24 SPIQ GPIO17 i 3 i
GPIO18 25 GPIO18 GPIO18 i 0 USB,G
GPIO19 26 GPIO19 GPIO19 i 0* USB
U0RXD 27 U0RXD GPIO20 i 3 G
U0TXD 28 U0TXD GPIO21 i 4 i
Reset
Thedefaultconfigurationofeachpinafterreset:
• 0 ⚶inputdisabled,inhighimpedancestate(IE=0)
• 1 ⚶inputenabled,inhighimpedancestate(IE=1)
• 2 ⚶inputenabled,pull-downresistorenabled(IE=1,WPD=1)
• 3 ⚶inputenabled,pull-upresistorenabled(IE=1,WPU=1)
• 4 ⚶outputenabled,pull-upresistorenabled(OE=1,WPU=1)
• 0* ⚶inputdisabled,pull-upresistorenabled(IE=0,WPU=0,USB_WPU=1). SeedetailsinNotes
• 1* ⚶WhenthevalueofeFusebitEFUSE_DIS_PAD_JTAGis
– 0,inputenabled,pull-upresistorenabled(IE=1,WPU=1)
EspressifSystems 13
Submit Document Feedback
Releasemaster
===PAGE 17===
Chapter1. LatestVersionofThisDocument
– 1,inputenabled,inhighimpedancestate(IE=1)
Notes
• R ⚶Thesepinshaveanalogfunctions.
• USB ⚶GPIO18andGPIO19areUSBpins.
– By default, the USB function is enabled for USB pins (i.e., GPIO18 and GPIO19), and
the pin pull-up is decided by the USB pull-up resistor. The USB pull-up resistor is
controlled by USB_SERIAL_JTAG_DP/DM_PULLUP and the pull-up value is controlled by
USB_SERIAL_JTAG_PULLUP_VALUE. For details, seeESP32-C3 Technical Reference Manual>
Chapter USB Serial/JTAG Controller.
– When the USB function is disabled, USB pins are used as regular GPIOs and the pinns internal weak
pull-upandpull-downresistorsaredisabledbydefault(configurablebyIO_MUX_FUN_WPU/WPD).
• G ⚶Thesepinshaveglitchesduringpower-up. SeedetailsinTable Power-Up Glitches on Pins.
Table6: Power-UpGlitchesonPins
Pin GlitchPage14,3 Typical Time (ns)
MTCK Low-levelglitch 5
MTDO Low-levelglitch 5
GPIO10 Low-levelglitch 5
U0RXD Low-levelglitch 5
GPIO18 High-levelglitch 50,000
1.3.11 ADC
Pleaseadda0.1μFfiltercapacitorbetweenESPpinsandgroundwhenusingtheADCfunctiontoimproveaccuracy.
It is recommend to use ADC1, given that ADC2 is not factory-calibrated, and ADC2 of some chip revisions is not
operable. Fordetails,pleasereferto ESP32-C3SeriesSoCErrata .
ThecalibratedADCresultsafterhardwarecalibrationand softwarecalibrationareshowninthelistbelow. Forhigher
accuracy,youmayimplementyourowncalibrationmethods.
• WhenATTEN=0andtheeffectivemeasurementrangeis0~750mV,thetotalerroris±10mV.
• WhenATTEN=1andtheeffectivemeasurementrangeis0~1050mV,thetotalerroris±10mV.
• WhenATTEN=2andtheeffectivemeasurementrangeis0~1300mV,thetotalerroris±10mV.
• WhenATTEN=3andtheeffectivemeasurementrangeis0~2500mV,thetotalerroris±35mV.
1.3.12 USB
ESP32-C3integratesaUSBSerial/JTAGcontrollerthatsupportsUSB2.0full-speeddevice.
GPIO18andGPIO19canbeusedasD-andD+ofUSBrespectively. Itisrecommendedtoreserveseriesresistors
(initial value can be 22/33 Ω) and capacitors to ground on the traces (initially can be unpopulated), and place them
closetothechip.
Note that upon power-up, the USB_D+ signal will fluctuate between high and low states. The high-level signal is
relativelystrongandrequiresarobustpull-downresistortodriveitlow. Therefore, ifyouneedastableinitialstate,
addinganexternalpull-upresistorisrecommendedtoensureaconsistenthigh-leveloutputvoltageatstartup.
ESP32-C3 also supports download functions and log message printing via USB. For details please refer to Section
Download Guidelines.
3
• Low-levelglitch: thepinisatalowleveloutputstatusduringthetimeperiod;
• High-levelglitch: thepinisatahighleveloutputstatusduringthetimeperiod.
EspressifSystems 14
Submit Document Feedback
Releasemaster
===PAGE 18===
Chapter1. LatestVersionofThisDocument
1.4 PCB Layout Design
ThischapterintroducesthekeypointsofhowtodesignanESP32-C3PCBlayoutusinganESP32-C3module(see
Figure ESP32-C3 Reference PCB Layout)asanexample.
Fig.10: ESP32-C3ReferencePCBLayout
1.4.1 General Principles of PCB Layout for the Chip
Itisrecommendedtouseafour-layerPCBdesign:
• Layer1(TOP):Signaltracesandcomponents.
• Layer2(GND):NosignaltracesheretoensureacompleteGNDplane.
• Layer3(POWER):GNDplaneshouldbeappliedtobetterisolatetheRFandcrystal. Routepowertracesand
afewsignaltracesonthislayer,providedthatthereisacompleteGNDplaneundertheRFandcrystal.
• Layer4(BOTTOM):Routeafewsignaltraceshere. Itisnotrecommendedtoplaceanycomponentsonthis
layer.
Atwo-layerPCBdesigncanalsobeused:
• Layer1(TOP):Signaltracesandcomponents.
• Layer2(BOTTOM):Donotplaceanycomponentsonthislayerandkeeptracestoaminimum. Pleasemake
surethereisacompleteGNDplaneforthechip,RF,andcrystal.
1.4.2 Power Supply
Four-Layer PCB Design
Figure ESP32-C3 Power Traces in a Four-Layer PCB Design showsthepowertracesinafour-layerPCBdesign.
• Afour-layerPCBdesignisrecommended. Wheneverpossible,routethepowertracesontheinnerlayers(not
thegroundlayer)andconnectthemtothechippinsthroughvias. Thereshouldbeatleasttwoviasifthemain
powertracesneedtocrosslayers. Thedrilldiameteronotherpowertracesshouldbenosmallerthanthewidth
ofthepowertraces.
EspressifSystems 15
Submit Document Feedback
Releasemaster
===PAGE 19===
Chapter1. LatestVersionofThisDocument
Fig.11: ESP32-C3PowerTracesinaFour-LayerPCBDesign
• The yellow highlighted traces in FigureESP32-C3 Power Traces in a Four-Layer PCB Design are the 3.3 V
powertraces. Thewidthofthemainpowertracesshouldbenolessthan25mil. ThewidthofVDD3P3power
traces should be no less than 20 mil. The recommended width of other power traces is 10 mil. Ensure the
powertracesaresurroundedbygroundcopper.
• The red circles inESP32-C3 Power Traces in a Four-Layer PCB Design show ESD protection diodes. Place
them close to the power input. Add a 10 µF capacitor before the power trace enters the chip. You can also
adda0.1 µFor1 µFcapacitorinparallel. Afterthat,thepowertracecanbranchoutinastar-shapedlayoutto
reducecouplingbetweendifferentpowerpins.
• Thepowersupplyforpin2andpin3isRFrelated,sopleaseplacea10µFcapacitorforeachpin. Youcanalso
adda0.1µFor1µFcapacitorinparallel.
• Add a CLC/LC filter circuit near pin2 and pin3 to suppress high-frequency harmonics. The power trace can
beroutedata45-degreeangletomaintaindistancefromadjacentRFtraces. Exceptforthe10µFcapacitor,
itisrecommendedtouse0201components. Thisallowsthefiltercircuitforpin2andpin3tobeplacedcloser
to the pins, with a GND isolation layer separating them from surrounding RF and GPIO traces, while also
maximizingtheplacementofgroundvias. Using0201componentsenablesplacingaviatothebottomlayerat
thefirstcapacitornearthechip,whilemaintainingakeep-outareaonotherlayers,furtherreducingharmonic
interference. SeeFigureESP32-C3 Power Traces in a Four-Layer PCB Design.
• In FigureESP32-C3 Power Traces in a Four-Layer PCB Design , the 10 µF capacitor is shared by the analog
power supply VDD3P3, and the power entrance since the analog power is close to the chip power entrance.
IfthechippowerentranceisnotnearVDD3P3,itisrecommendedtoadda10µFcapacitortoboththechip
powerentranceandVDD3P3.
• Place appropriate decoupling capacitors at the rest of the power pins. Ground vias should be added close to
thecapacitor nsgroundpadtoensureashortreturnpath.
• Thegroundpadatthebottomofthechipshouldbeconnectedtothegroundplanethroughatleastnineground
vias.
• The ground pads of the chip and surrounding circuit components should make full contact with the ground
copperpourratherthanbeingconnectedviatraces.
• If you need to add a thermal pad EPAD under the chip on the bottom of the module, it is recommended to
employ a square grid on the EPAD, cover the gaps with solder paste, and place ground vias in the gaps, as
shown in FigureESP32-C3 Power Traces in a Four-Layer PCB Design . This helps effectively reduce solder
leakageissueswhensolderingthemoduleEPADtothesubstrate.
• Foroptimalgrounding,connecttheEPADtoalargeexternalgroundareausingwidetracesorcopperplanes.
Two-Layer PCB Design
Figure ESP32 Power Traces in a Two-Layer PCB Design showsthepowertracesinatwo-layerPCBdesign.
EspressifSystems 16
Submit Document Feedback
Releasemaster
===PAGE 20===
Chapter1. LatestVersionofThisDocument
Fig.12: ESP32PowerTracesinaTwo-LayerPCBDesign
• Foratwo-layerdesign,ensuretoprovideacontinuousreferencegroundforthechip,RF,andcrystaloscillator,
asshowninthefigureabove.
• Inthefigureabove,thetraceVDD33representsthe3.3Vpowertrace. Unlikeafour-layerdesign,thepower
trace should be routed on the top layer as much as possible. Therefore, the thermal pad in the center of the
chipshouldbereducedinsize,allowingthepowertracetopassbetweenthesignalpadsandthethermalpad.
Viastothebottomlayershouldonlybeusedwhenabsolutelynecessary.
• Otherlayoutconsiderationsarethesameasforafour-layerdesign.
• Notethattherearenoofficialtwo-layermodules. ThefigureaboveusestheESP32moduleasanexample.
1.4.3 Crystal
Figure ESP32-C3 Crystal Layout (without Keep-out Area on Top Layer) shows the layout for the crystal that is con-
nectedtothegroundthroughviasbutthereisnokeep-outareaonthetoplayerforgroundisolation.
Thelayoutofthecrystalshouldfollowtheguidelinesbelow:
• EnsureacompleteGNDplanefortheRF,crystal,andchip.
• Thecrystalshouldbeplacedfarfromtheclockpintoavoidinterferenceonthechip. Thegapshouldbeatleast
2.0mm. Itisgoodpracticetoaddhigh-densitygroundviasstitchingaroundtheclocktraceforbetterisolation.
• Thereshouldbenoviasfortheclockinputandoutputtraces.
• Componentsinseriestothecrystaltraceshouldbeplacedclosetothechipside.
• Theexternalmatchingcapacitorsshouldbeplacedonthetwosidesofthecrystal,preferablyattheendofthe
clock trace, but not connected directly to the series components. This is to make sure the ground pad of the
capacitorisclosetothatofthecrystal.
• Donotroutehigh-frequencydigitalsignaltracesunderthecrystal. Itisbestnottorouteanysignaltraceunder
thecrystal. Theviasonthepowertracesonbothsidesofthecrystalclocktraceshouldbeplacedasfaraway
fromtheclocktraceaspossible,andthetwosidesoftheclocktraceshouldbesurroundedbygroundcopper.
• Asthecrystalisasensitivecomponent,donotplaceanymagneticcomponentsnearbythatmaycauseinterfer-
ence,forexamplelargeinductancecomponent,andensurethatthereisacleanlarge-areagroundplanearound
thecrystal.
EspressifSystems 17
Submit Document Feedback
Releasemaster
===PAGE 21===
Chapter1. LatestVersionofThisDocument
Fig.13: ESP32-C3CrystalLayout(withoutKeep-outAreaonTopLayer)
1.4.4 RF
TheRFtraceisroutedasshownhighlightedinpinkinFigure ESP32-C3 RF Layout in a Four-layer PCB Design.
Fig.14: ESP32-C3RFLayoutinaFour-layerPCBDesign
TheRFlayoutshouldmeetthefollowingguidelines:
• The RF trace should have a 50 Ω characteristic impedance. The reference plane is the layer next to the chip.
FordesigningtheRFtraceat50Ωimpedance,youcouldrefertothePCBstack-updesignshownbelow.
• ACLCmatchingcircuitisrequiredforchiptuning. Pleaseuse0201componentsandplacethemclosetothe
pin in a zigzag. In other words, the two capacitors should not be oriented in the same direction to minimize
interference.
• Addastubonthegroundpadofthegroundingcapacitornearthechipsideinthematchingcircuittosuppress
thesecondharmonics. Itispreferabletokeepthestublength15mil,anddeterminethestubwidthaccording
to the PCB stack-up so that the characteristic impedance of the stub is 100 Ω ± 10%. The reference plane
EspressifSystems 18
Submit Document Feedback
Releasemaster
===PAGE 22===
Chapter1. LatestVersionofThisDocument
Fig.15: ESP32-C3PCBStack-upDesign
is the third layer, so the area under the trace on the second layer should be cleared. The trace highlighted in
Figure ESP32-C3 Stub in a Four-layer PCB Design is the stub. Note that a stub is not required for package
typesof0402andabove.
• ForPCBantennas,makesuretovalidatethemthroughbothsimulationandreal-worldtestingonadevelopment
board. ItisrecommendedtoincludeanadditionalCLCmatchingcircuitforantennatuning. Placethiscircuit
asclosetotheantennaaspossible.
• The RF trace should have a consistent width and not branch out. It should be as short as possible with dense
groundviasaroundforinterferenceshielding.
• TheRFtraceshouldberoutedontheouterlayerwithoutvias,i.e.,shouldnotcrosslayers. TheRFtraceshould
beroutedata135°angle,orwithcirculararcsiftracebendsarerequired.
• The ground plane on the adjacent layer needs to be complete. Do not route any traces under the RF trace
wheneverpossible.
• There should be no high-frequency signal traces routed close to the RF trace. The RF antenna should be
placedawayfromhigh-frequencycomponents,suchascrystals,DDRSDRAM,high-frequencyclocks,etc. In
addition,theUSBport,USB-to-serialchip,UARTsignallines(includingtraces,vias,testpoints,headerpins,
etc.) mustbeasfarawayfromtheantennaaspossible. TheUARTsignallineshouldbesurroundedbyground
copperandgroundvias.
1.4.5 Flash
Thelayoutforflashshouldfollowtheguidelinesbelow:
• Placethezero-ohmresistorsinseriesontheSPIlinesclosetoESP32-C3.
• Route the SPI traces on the inner layer (e.g., the third layer) whenever possible, and add ground copper and
groundviasaroundtheclockanddatatracesofSPIseparately.
EspressifSystems 19
Submit Document Feedback
Releasemaster
===PAGE 23===
Chapter1. LatestVersionofThisDocument
Fig.16: ESP32-C3StubinaFour-layerPCBDesign
• If the flash and PSRAM are located far from ESP32-C3, it is recommended to place appropriate decoupling
capacitorsbothatVDD_SPIandneartheflashandPSRAMpowersupply.
Figure ESP32-C3 Quad SPI Flash Layout showsthequadSPIflashlayout.
Fig.17: ESP32-C3QuadSPIFlashLayout
1.4.6 UART
Figure ESP32-C3 UART LayoutshowstheUARTlayout.
TheUARTlayoutshouldmeetthefollowingguidelines:
• TheseriesresistorontheU0TXDtraceneedstobeplacedclosetothechipsideandawayfromthecrystal.
• TheU0TXDandU0RXDtracesonthetoplayershouldbeasshortaspossible.
EspressifSystems 20
Submit Document Feedback
Releasemaster
===PAGE 24===
Chapter1. LatestVersionofThisDocument
Fig.18: ESP32-C3UARTLayout
• TheUARTtraceshouldbesurroundedbygroundcopperandgroundviasstitching.
1.4.7 General Principles of PCB Layout for Modules (Positioning a Module on a Base
Board)
Ifmodule-on-boarddesignisadopted,attentionshouldbepaidwhilepositioningthemoduleonthebaseboard. The
interferenceofthebaseboardonthemodule nsantennaperformanceshouldbeminimized.
It is suggested to place the modulens on-board PCB antenna outside the base board, and the feed point of the
antenna close to the edge of the base board. In the following example figures, positions with mark✓ are strongly
recommended,whilepositionswithoutamarkarenotrecommended.
Fig.19: PlacementofESP32-C3ModulesonBaseBoard(antennafeedpointontheright)
Iftheantennacannotextendbeyondtheboardedge,thefeedpointshouldstillbeplacedasclosetotheboardedge
as possible. Then cut off the base board on both sides of the antenna and below it to minimize the impact of the
base board material on the PCB antenna and provide a sufficiently large clearance area for the PCB antenna. Note
that the module should not be placed in the center of the board with clearance created by hollowing out on all four
EspressifSystems 21
Submit Document Feedback
Releasemaster
===PAGE 25===
Chapter1. LatestVersionofThisDocument
Fig.20: PlacementofESP32-C3ModulesonBaseBoard(antennafeedpointontheleft)
sides. FigureKeepout Zone for ESP32-C3 Module ns Antenna (Antenna feed point on the Left) shows thesuggested
clearance area. Please note that sufficient ground copper and dense ground vias should be placed on the base board
neartheantenna.
After the base board is placed in the end product, please consider the impact of the housing on the antenna during
end-productdesign. EnsurethatthePCBantennaonthebaseboardalsohasasufficientlylargeclearanceareainside
thehousing. Aclearanceofatleast15mmisrecommendedinalldirections.
PleasenotethatthefinalendproductshouldbetestedforthroughputandcommunicationrangetoensureRFperfor-
mance.
1.4.8 USB
TheUSBlayoutshouldmeetthefollowingguidelines:
• ReservespaceforresistorsandcapacitorsontheUSBtracesclosetothechipside.
• Usedifferentialpairsandroutetheminparallelatequallengths. Maintainadifferentialpairimpedanceof90
Ωwithatoleranceof±10%.
• USBdifferentialtracesshouldminimizeviatransitionsasmuchaspossibletoensurebetterimpedancecontrol
andavoidsignalreflections. Ifviasarenecessary,addapairofgroundreturnviasateachtransitionpoint.
• Ensurethereisacontinuousreferencelayer(agroundlayerisrecommended)beneaththeUSBtraces.
• SurroundtheUSBtraceswithgroundcopper.
1.4.9 Typical Layout Problems and Solutions
When ESP32-C3 sends data packages, the voltage ripple is small, but RF TX performance is poor.
Analysis: The RF TX performance can be affected not only by voltage ripples, but also by the crystal itself. Poor
qualityandbigfrequencyoffsetsofthecrystaldecreasetheRFTXperformance. Thecrystalclockmaybecorrupted
by other interfering signals, such as high-speed output or input signals. In addition, high-frequency signal traces,
such as the SDIO traces and UART traces under the crystal, could also result in the malfunction of the crystal.
Besides, sensitive components or radiating components, such as inductors and antennas, may also decrease the RF
performance.
EspressifSystems 22
Submit Document Feedback
Releasemaster
===PAGE 26===
Chapter1. LatestVersionofThisDocument
Fig.21: KeepoutZoneforESP32-C3Module nsAntenna(AntennafeedpointontheLeft)
Solution: Thisproblemiscausedbyimproperlayoutforthecrystalandcanbesolvedbyre-layout. Pleasereferto
Section Crystalfordetails.
When ESP32-C3 sends data packages, the power value is much higher or lower than the target power value,
and the EVM is relatively poor.
Analysis: The disparity between the tested value and the target value may be due to signal reflection caused by
the impedance mismatch on the transmission line connecting the RF pin and the antenna. Besides, the impedance
mismatchwillaffecttheworkingstateoftheinternalPA,makingthePAprematurelyaccessthesaturatedregionin
anabnormalway. TheEVMbecomespoorasthesignaldistortionhappens.
Solution: Match the antennans impedance with the π-type circuit on the RF trace, so that the impedance of the
antennaasseenfromtheRFpinmatchescloselywiththatofthechip. Thisreducesreflectionstotheminimum.
TX performance is not bad, but the RX sensitivity is low.
Analysis: Good TX performance indicates proper RF impedance matching. Poor RX sensitivity may result from
external coupling to the antenna. For instance, the crystal signal harmonics could couple to the antenna. If the TX
and RX traces of UART cross over with RF trace, they will affect the RX performance, as well. If there are many
high-frequencyinterferencesourcesontheboard,signalintegrityshouldbeconsidered.
Solution: Keep the antenna away from crystals. Do not route high-frequency signal traces close to the RF trace.
PleaserefertoSection RF fordetails.
1.5 Download Guidelines
EspressifSystems 23
Submit Document Feedback
Releasemaster
===PAGE 27===
Chapter1. LatestVersionofThisDocument
YoucandownloadfirmwaretoESP32-C3viaUARTandUSB.
TodownloadviaUART:
1. Beforethedownload, makesureto setthechipormoduletoJointDownloadBootmode, accordingtoTable
Boot Mode Control.
2. Power up the chip or module and check the log via the UART0 serial port. If the log showsowaiting for
downloadp,thechipormodulehasenteredJointDownloadBootmode.
3. Usethe Flash Download Tool toflashfirmwareintoflashviaUART.
4. After the firmware has been downloaded, pull GPIO9 high or leave it floating to make sure that the chip or
moduleentersSPIBootmode.
5. Powerupthechipormoduleagain. Thechipwillreadandexecutethenewfirmwareduringinitialization.
TodownloadviaUSB:
1. If the flash is empty, set the chip or module to Joint Download Boot mode, according to TableBoot Mode
Control.
2. PowerupthechipormoduleandcheckthelogviaUSBserialport. Ifthelogshows owaitingfordownload p
,thechipormodulehasenteredJointDownloadBootmode.
3. Usethe Flash Download Tool toflashfirmwareintoflashviaUSB.
4. After the firmware has been downloaded, pull GPIO9 high or leave it floating to make sure that the chip or
moduleentersSPIBootmode.
5. Powerupthechipormoduleagain. Thechipwillreadandexecutethenewfirmwareduringinitialization.
6. Iftheflashisnotempty,startdirectlyfromStep3.
Note:
• Forfirmwaredownloadinstructions,seealso ESPProductFirmwareDownloadInstructions .
• Forhowtocheckserialportoutput,seealso EstablishSerialConnectionwithESP32-C3 .
• Itisadvisedtodownloadthefirmwareonlyafterthe owaitingfordownload plogshowsviatheserialport.
• SerialtoolscannotbeusedsimultaneouslywiththeFlashDownloadToolononeCOMport.
• TheUSBauto-downloadwillbedisabledifthefollowingconditionsoccurintheapplication,whereitwillbe
necessarytosetthechipormoduletoJointDownloadBootmodefirstbyconfiguringthestrappingpin.
– USBPHYisdisabledbytheapplication;
– USBisconfiguredforotherUSBfunctions,e.g.,USBhost,USBstandarddevice;
– USBIOsareconfiguredtootherperipherals,suchasUARTandLEDC.
• ItisrecommendedthattheuserretainscontrolofthestrappingpinstoavoidtheUSBdownloadfunctionnot
beingavailableincaseoftheabovescenario.
• ItisrecommendedtoretaintheUARTdownloadinterface, asthecurrentRFtestfirmwareonlysupportsthe
UARTinterface.
1.6 Related Documentation and Resources
1.6.1 ESP32-C3 Modules
Thissectionlistsonlysampleandmass-productionESP32-C3modules. Forthecompletelist,seethe Modulespage
ontheEspressifwebsite.
• ESP32-C3-MINI-1
• ESP32-C3-MINI-1U
• ESP32-C3-WROOM-02
EspressifSystems 24
Submit Document Feedback
Releasemaster
===PAGE 28===
Chapter1. LatestVersionofThisDocument
• ESP32-C3-WROOM-02U
• ESP8685-WROOM-01
• ESP8685-WROOM-03
• ESP8685-WROOM-04
• ESP8685-WROOM-05
• ESP8685-WROOM-06
• ESP8685-WROOM-07
Formodulereferencedesignspleasereferto:
• Downloadlinks
Note: Usethefollowingtoolstoopenthefilesinmodulereferencedesigns:
• .DSNfiles: OrCADCaptureV16.6
• .pcb files: Pads Layout VX.2. If you cannot open the .pcb files, please try importing the .asc files into your
softwaretoviewthePCBlayout.
Forthetermsapplicabletotheuseofthesereferencedesigns,pleasereferto Terms of Use for Reference Designsin
Disclaimer and Copyright Notice.
1.6.2 ESP32-C3 Development Boards
This section lists only sample and mass-production ESP32-C3 development boards. For the complete list, see the
DevelopmentBoards pageontheEspressifwebsite.
• ESP32-C3-AWS-ExpressLink-DevKit-2
• ESP32-C3-DevKit-RUST-2
• ESP32-C3-DevKitM-1
• ESP32-C3-LCDkit
1.6.3 Other Related Documentation and Resources
• ChipDatasheet(PDF)
• TechnicalReferenceManual(PDF)
• ChipErrata
• ESP32-C3ChipVariants
• EspressifKiCadLibrary
• ESPProductSelector
• RegulatoryCertificates
• UserForum(Hardware)
• TechnicalSupport
• ESP-FAQ
1.7 Glossary
Theglossarycontainstermsandacronymsthatareusedinthisdocument.
EspressifSystems 25
Submit Document Feedback
Releasemaster
===PAGE 29===
Chapter1. LatestVersionofThisDocument
Term Description
CLC Capacitor-Inductor-Capacitor
DDRSDRAM DoubleDataRateSynchronousDynamicRandom-AccessMemory
ESD ElectrostaticDischarge
LC Inductor-Capacitor
PA PowerAmplifier
RC Resistor-Capacitor
RTC Real-TimeClock
Zero-ohmresistor Azero-ohmresistoractsasaplaceholderinthecircuit,allowingforthereplacementwith
ahigher-ohmresistorbasedonspecificdesignrequirements.
1.8 Revision History
EspressifSystems 26
Submit Document Feedback
Releasemaster
===PAGE 30===
Chapter1. LatestVersionofThisDocument
Table7: RevisionHistory
Date Version Release Notes
2025-06-05 v1.8
•PCB Layout Design
– Section USB: Updated descriptions about the USB layout
guidelines
2025-05-23 v1.7
•PCB Layout Design
– Section Crystal: Updateddescriptionsaboutthecrystallayout
guidelines
2025-01-07 v1.6
•ESP32-C3 Modulesğ
– Addeddownloadlinkstomodulereferencedesigns
2024-11-15 v1.5
•Schematic Checklist
– Section SPI:Newlyaddedsection
2024-10-15 v1.4
•Schematic Checklist
– Section UART:UpdatedtheATrelateddescription
2024-02-18 v1.3
•PCB Layout Design
– Section General Principles of PCB Layout for Modules (Posi-
tioning a Module on a Base Board): UpdatedFigurePlacement
of ESP32-C3 Modules on Base Board (antenna feed point on
the right)andFigure Placement of ESP32-C3 Modules on Base
Board (antenna feed point on the left)
2024-01-09 v1.2
•Schematic Checklist
– Section RF Tuning: UpdatedRFmatchingdescription
2023-12-25 v1.1
•PCB Layout Design
– Section Crystal: UpdatedcrystalPCBlayout
2023-12-22 v1.0 Migrated ESP32-C3 Hardware Design Guidelines from PDF to HTML for-
mat. During the migration from PDF to HTML format, minor updates, im-
provements, and clarifications were made throughout the documentation. If
youwouldliketocheckpreviousversionsofthedocument,pleasesubmitdoc-
umentationfeedback.
1.9 Disclaimer and Copyright Notice
Informationinthisdocument,includingURLreferences,issubjecttochangewithoutnotice.
Allthirdparty nsinformationinthisdocumentisprovidedasiswithnowarrantiestoitsauthenticityandaccuracy.
Nowarrantyisprovidedtothisdocumentforitsmerchantability,non-infringement,fitnessforanyparticularpurpose,
nordoesanywarrantyotherwisearisingoutofanyproposal,specificationorsample.
All liability, including liability for infringement of any proprietary rights, relating to use of information in this doc-
umentisdisclaimed. Nolicensesexpressorimplied,byestoppelorotherwise,toanyintellectualpropertyrightsare
EspressifSystems 27
Submit Document Feedback
Releasemaster
===PAGE 31===
Chapter1. LatestVersionofThisDocument
grantedherein.
TheWi-FiAllianceMemberlogoisatrademarkoftheWi-FiAlliance. TheBluetoothlogoisaregisteredtrademark
ofBluetoothSIG.
Alltradenames, trademarksandregisteredtrademarksmentionedinthisdocumentarepropertyoftheirrespective
owners,andareherebyacknowledged.
1.9.1 Terms of Use for Reference Designs
Themodulereferencedesignsprovidedinthisdocumentationareopen-sourcematerialsandmaybeusedinproduct
development,includingcommercialapplications,providedthatappropriateproductverificationandtestingarecarried
outpriortouse.
UseofthesereferencedesignsdoesnotgrantanyrightstouseEspressif nstrademarks. Inparticular:
• Prior to incorporating a reference design into a product, any Espressif trademarks appearing on the PCB
silkscreen,suchastheEspressiflogoormodulepartnumbers,mustbereplacedwiththemanufacturer nsown
markings.
• WheretheschematicsorPCBlayoutaremodifiedandtheresultingdesignisreleasedforcommercialuse,all
Espressiftrademarksandotherproprietarymarkingsmustlikewiseberemovedfromthereleasedschematics
andPCBfiles.
EspressifSystems 28
Submit Document Feedback
Releasemaster

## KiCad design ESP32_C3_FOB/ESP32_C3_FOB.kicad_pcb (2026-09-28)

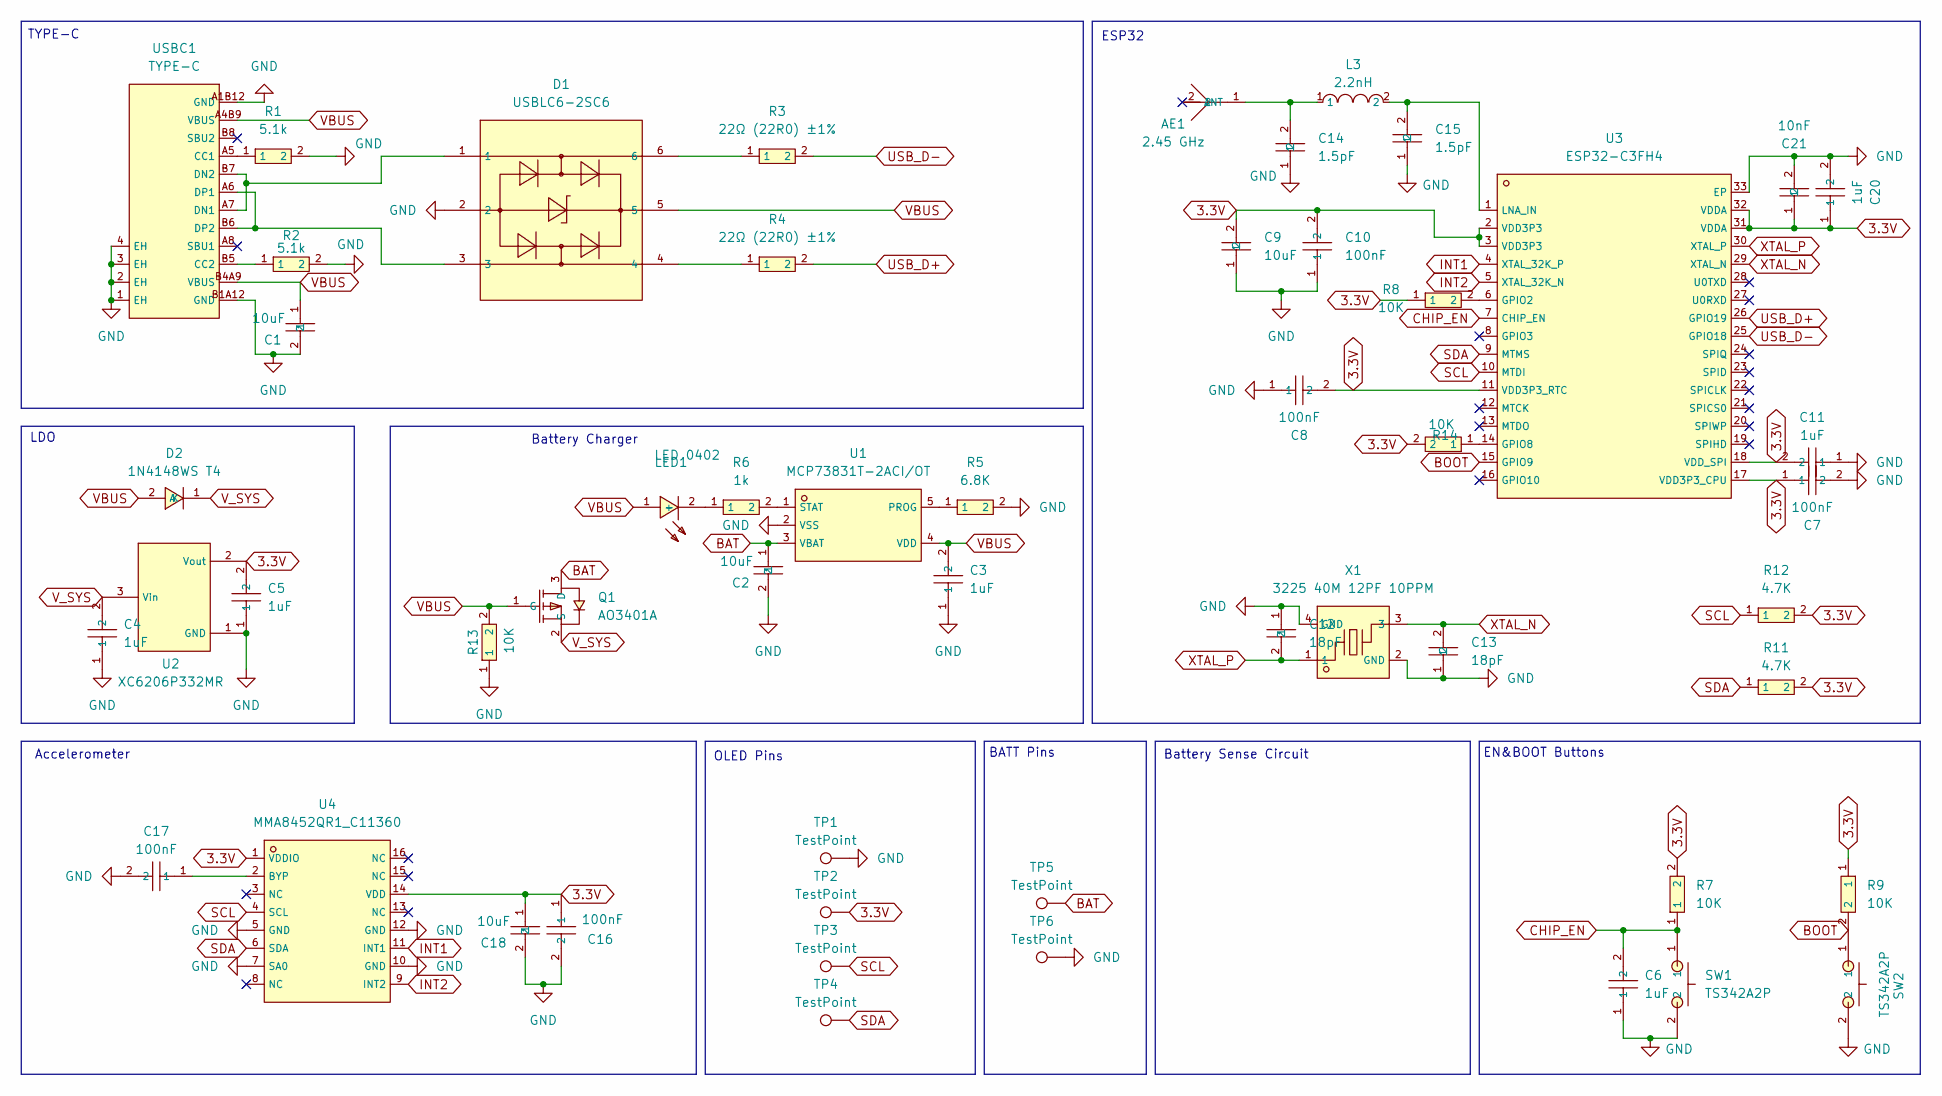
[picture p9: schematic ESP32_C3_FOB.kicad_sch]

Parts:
AE1: 2.45 GHz; C89334_ANT-SMD_L3_2-W1_6; LCSC C89334
C1, C2, C9, C18: 10uF; C15525_C0402; LCSC C15525
C3, C4, C5, C6, C11, C20: 1uF; C52923_C0402; LCSC C52923
C7, C8, C10, C16, C17: 100nF; C1525_C0402; LCSC C1525
C12, C13: 18pF; C1549_C0402; LCSC C1549
C14, C15: 1.5pF; C1552_C0402; LCSC C1552
C21: 10nF; C15195_C0402; LCSC C15195
D1: USBLC6-2SC6; C7519_SOT-23-6_L2_9-W1_6-P0_95-LS2_8-BL; LCSC C7519
D2: 1N4148WS T4; C2128_SOD-323_L1_8-W1_3-LS2_5-RD; LCSC C2128
L3: 2.2nH; C27122_L0402; LCSC C27122
LED1: LED 0402; C71911_LED0402-R-RD; LCSC C71911
Q1: AO3401A; C15127_SOT-23_L2_9-W1_3-P1_90-LS2_4-BR; LCSC C15127
R1, R2: 5.1k; C25905_R0402; LCSC C25905
R3, R4: 22Ω (22R0) ±1%; C25092_R0402; LCSC C25092
R5: 6.8K; C25917_R0402; LCSC C25917
R6: 1k; C11702_R0402; LCSC C11702
R7, R8, R9, R13, R14: 10K; C25744_R0402; LCSC C25744
R11, R12: 4.7K; C25900_R0402; LCSC C25900
SW1, SW2: TS342A2P; C398055_SW-SMD_L4_0-W3_0-LS5_0-EH; LCSC C398055
TP1, TP2, TP3, TP4, TP5, TP6: TestPoint; TestPoint_Pad_1.5x1.5mm
U1: MCP73831T-2ACI/OT; C424093_SOT-23-5_L3_0-W1_7-P0_95-LS2_8-BL; LCSC C424093
U2: XC6206P332MR; C5446_SOT-23-3_L2_9-W1_6-P1_90-LS2_8-BR; LCSC C5446
U3: ESP32-C3FH4; C2858491_QFN-32_L5_0-W5_0-P0_50-TL-EP3_7; LCSC C2858491
U4: MMA8452QR1_C11360; C11360_QFN-16_L3_0-W3_0-P0_50-TL_MMA8452QR1; LCSC C11360
USBC1: TYPE-C; C165948_USB-C_SMD-TYPE-C-31-M-12_1; LCSC C165948
X1: 3225 40M 12PF 10PPM; C5380316_CRYSTAL-SMD_4P-L3_2-W2_5-BL; LCSC C5380316

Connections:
3.3V: C5.2, C7.1, C8.2, C9.2, C10.2, C11.2, C16.1, C18.1, C20.1, C21.1, R7.2, R8.1, R9.1, R11.2, R12.2, R14.2, TP2.1 (1_1), U2.2 (Vout), U3.2 (VDD3P3), U3.3 (VDD3P3), U3.11 (VDD3P3_RTC), U3.17 (VDD3P3_CPU), U3.18 (VDD_SPI), U3.31 (VDDA), U3.32 (VDDA), U4.1 (VDDIO), U4.14 (VDD)
BAT: C2.1, Q1.3 (D), TP5.1 (1_1), U1.3 (VBAT)
BOOT: R9.2, SW2.1, U3.15 (GPIO9)
CHIP_EN: C6.2, R7.1, SW1.1, U3.7 (CHIP_EN)
GND: C1.2, C2.2, C3.1, C4.1, C5.1, C6.1, C7.2, C8.1, C9.1, C10.1, C11.1, C12.1, C13.1, C14.1, C15.1, C16.2, C17.2, C18.2, C20.2, C21.2, D1.2, R1.2, R2.2, R5.2, R13.1, SW1.2, SW2.2, TP1.1 (1_1), TP6.1 (1_1), U1.2 (VSS), U2.1 (GND), U3.33 (EP), U4.5 (GND), U4.7 (SA0), U4.10 (GND), U4.12 (GND), USBC1.1 (EH), USBC1.2 (EH), USBC1.3 (EH), USBC1.4 (EH), USBC1.A1B12 (GND), USBC1.B1A12 (GND), X1.2 (GND), X1.4 (GND)
INT1: U3.4 (XTAL_32K_P), U4.11 (INT1)
INT2: U3.5 (XTAL_32K_N), U4.9 (INT2)
unnamed: AE1.1 (ANT_1), C14.2, L3.1
unnamed: D1.4, R4.1
unnamed: D1.6, R3.1
unnamed: LED1.2 (-), R6.1
unnamed: R5.1, U1.5 (PROG)
unnamed: R6.2, U1.1 (STAT)
unnamed: R8.2, U3.6 (GPIO2)
unnamed: R14.1, U3.14 (GPIO8)
unnamed: C15.2, L3.2, U3.1 (LNA_IN)
unnamed: C17.1, U4.2 (BYP)
unnamed: R1.1, USBC1.A5 (CC1)
unnamed: R2.1, USBC1.B5 (CC2)
unnamed: D1.1, USBC1.A7 (DN1), USBC1.B7 (DN2)
unnamed: D1.3, USBC1.A6 (DP1), USBC1.B6 (DP2)
SCL: R12.1, TP3.1 (1_1), U3.10 (MTDI), U4.4 (SCL)
SDA: R11.1, TP4.1 (1_1), U3.9 (MTMS), U4.6 (SDA)
USB_D+: R4.2, U3.26 (GPIO19)
USB_D-: R3.2, U3.25 (GPIO18)
VBUS: C1.1, C3.2, D1.5, D2.2 (A), LED1.1 (+), Q1.1 (G), R13.2, U1.4 (VDD), USBC1.A4B9 (VBUS), USBC1.B4A9 (VBUS)
V_SYS: C4.2, D2.1 (K), Q1.2 (S), U2.3 (Vin)
XTAL_N: C13.2, U3.29 (XTAL_N), X1.3
XTAL_P: C12.2, U3.30 (XTAL_P), X1.1

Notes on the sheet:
LDO
Accelerometer
TYPE-C
EN&BOOT Buttons
ESP32
BATT Pins
OLED Pins
Battery Sense Circuit
Battery Charger

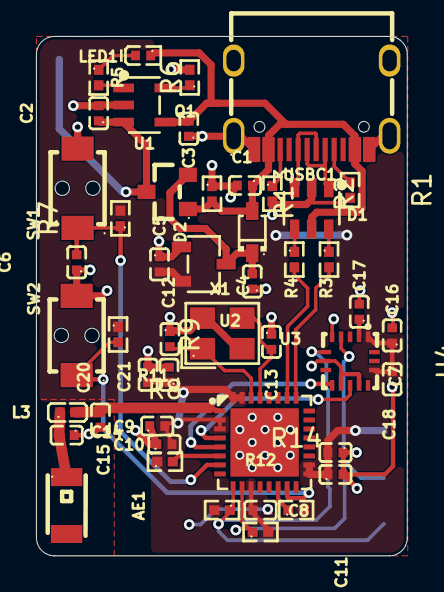
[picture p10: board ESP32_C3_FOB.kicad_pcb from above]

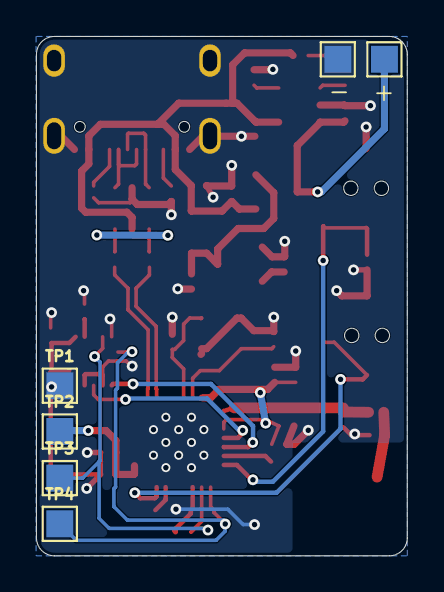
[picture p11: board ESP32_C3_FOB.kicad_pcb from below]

Board: 2 copper layers, 20.6 x 28.9 mm, 53 parts (6 on the bottom side), 29 nets.

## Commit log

2026-09-28 Add parametric watch keychain bumper (STEP/STL, placeholder dims)
    Claude-Session: https://claude.ai/code/session_01WbPyaM4PV82cRyowhKWz1U
    [watch_keychain_bumper.step, watch_keychain_bumper.stl]
2026-09-28 Size keychain bumper for HUAWEI Band 6 (43 x 25.4 x 10.99 mm), add fit-test ring
    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
    [fit_test_ring.stl, watch_keychain_bumper.step, watch_keychain_bumper.stl]
2026-09-28 added STL files
    [22mm_adaptor_for_huawei_band_6_v13.stl]
2026-09-28 Rebuild keychain case from Band 6 reference geometry: no strap mounts, flat ends, keyring loop
    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
    [band6_keychain_case.step, band6_keychain_case.stl, fit_test_ring.stl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]
2026-10-01 Keychain case: move keyring loop to the other end, shorten it to a 5.4 mm slot tab
    The loop was on the wrong end relative to the button. It is now on the -Z end
    (RING_END switch to swap back), and the tall round eye is replaced by a short
    tab with a 7 x 3 mm slot, cutting the overall length from 59.6 to 54.9 mm.
    Claude-Session: https://claude.ai/code/session_01G9cBgRZ6ceCvDVxAkk4X38
    [band6_keychain_case.step, band6_keychain_case.stl]
2026-10-01 Keychain case: use a round keyring eye instead of the slot tab
    Same 9 mm / 4.6 mm round eye as before, without the triangular base, pulled
    in close to the case so it sticks out 7.2 mm (was about 10 mm originally).
    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
    [band6_keychain_case.step, band6_keychain_case.stl]
2026-10-01 Keychain case: restore the triangular gusset under the round eye
    Keeps the eye pulled in close to the case (7.2 mm past the end face).
    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
    [band6_keychain_case.step, band6_keychain_case.stl]
2026-10-01 Keychain case: round the four outer corners to 5 mm radius
    The 1 mm wall is kept at the corners (min 0.98 mm). The keyring gusset is
    narrowed to 17 mm so it stays on the flat part of the end.
    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
    [band6_keychain_case.step, band6_keychain_case.stl]
2026-10-01 Keychain case: add inward back ledge, add BTN_SIDE switch
    A 0.8 mm lip round the back edge stops the watch when it is pushed in from
    the screen side and keeps it from falling out the back. It is added below
    the old back face, so the watch height and tongue alignment are unchanged.
    The button opening stays on the +X wall: right of the keyring when the ring
    is on top and the screen faces you. Preview now shows that orientation.
    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
    [band6_keychain_case.step, band6_keychain_case.stl]
2026-10-01 Keychain case: keep the back ledge on the long sides only
    The ledge on the short ends stopped the watch from being tilted in past the
    end tongues. Long-side ledge still stops it falling out the back.
    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
    [band6_keychain_case.step, band6_keychain_case.stl]
